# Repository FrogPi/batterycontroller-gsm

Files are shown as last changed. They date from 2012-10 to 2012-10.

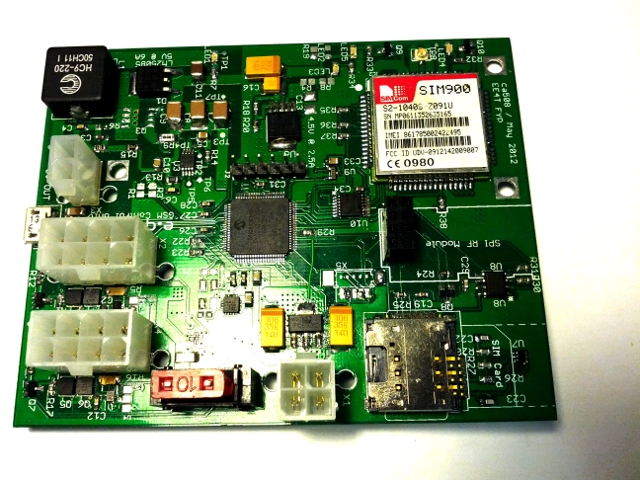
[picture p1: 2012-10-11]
media/proto.jpg

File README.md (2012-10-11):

# GSM Battery Box Monitoring and Control Board

Electrial Engineering Final Year Project Deliverable

Charith Amarasinghe 2012 <ca508@ic.ac.uk>

GSM Controller Prototype

## Features

* 1x Metered 12V Input/Output (Battery Connection)
* 2x Metered 12V Input/Outputs (Device Connection) with 4x IO pins each
* 1x 5V/3A USB Compliant Output
* Integrated SIMCOM SIM900 GSM Modem with U.FL Antenna Connector
* SPI interface for nRF24L01 RF module
* Integrated SIM and MicroSD socket
* RTCC Battery Backup
* PIC24FJ256GB106 Microcontroller with PICKit3 debug port
* microUSB OTG Port

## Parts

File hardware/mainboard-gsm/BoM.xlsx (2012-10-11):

C7 | 1843166 | 1812 Capacitor 22uF MLCC X5R | 4 | SIK
C8
C9
R14 | 1170981 | 0603 88.7K Resistor £0.011 | 50
R13 | 1652973 | 2.37k Resistor 0805 £0.082 | 4
C6 | 1740627 (http://onecall.farnell.com/avx/06031c102jat2a/capacitor-mlcc-0603-100v-1nf/dp/1740627) | 1000pF Capacitor 0603 £0.036 | 10
C10 |  | 1uF 0805 Capacitor
R9 | 1099907 | 10mOhm Resistor 1206 £0.28 | 5
C5 | 1907325 | 470nF 0805 £0.058 | 10
D1 | 9101055 | Diode Vishay 6CWO04 £1.16 | 2 | SOL
Q3 | 2101443 | MOSFET Si4401 £1.15 | 2 | SOL
L1 | 2075650 | Coiltronics 22uH Inductor £1.48 | 2 | SOL
R6 | 1399961 | 68K resistor £0.047 | 10
C4 | 1658867 | 3300pF Capacitor £0.083 | 10
R11 | 1653284 | 10K resistor £0.016 | £10.00
R15 | 1160169 | 3.4K resistor £0.32 | 5
C11 | 1907361 | 100uF Capacitor £1.07 | 5
C13 | 1658149 | 100uF Capacitor £0.195 | 5
R18 | 1170963 (http://onecall.farnell.com/multicomp/mc-0-063w-0603-1-57k6/resistor-0603-57k6/dp/1170963) | 57.6K Resistor £0.011 | 50
R20 | 2059637 (http://onecall.farnell.com/panasonic/erj3geyj223v/resistor-0603-22k-5-0-1w/dp/2059637) | 22K Resistor £0.007 | 50
C16 | 1658149 | See abv
C17 | CA06884 | 10uF Capacitor £0.19 | 10
U6 | 1822373 | Micrel LDO 3A £1.62 | 2
U5 | 2057285 | NX1117 3V3 £0.179 | 3
C14 | CA06884 | See abv
C15 | CA06884 | See abv
 | 1717778 | 2.7ohm Resistor | 5
 | 1857353 | IRFHM9331PbF £0.24 | 10
 | 1621962 | Welwyn 0.002ohm Resistor £0.33 | 5
 | 1453876 | Fuse Holder (Mini Blade) £1.6 | 2
 | 2008366 (http://onecall.farnell.com/bourns/cr0603-jw-104glf/resistor-0603-100k-5-0-1w/dp/2008366) | 100K Resistor 0603 £.009 | 50
 | 2008360 (http://onecall.farnell.com/bourns/cr0603-jw-103elf/resistor-0603-10k-5-0-1w/dp/2008360) | 10K Resistor 0603 £0.009 | 50
 | 1894721 | 2n7002 NFET £0.02 | 10
 | 2059640 (http://onecall.farnell.com/panasonic/erj3geyj303v/resistor-0603-30k-5-0-1w/dp/2059640) | 30K Resistor 0603 £0.007 | 50
 | 1833812 (http://onecall.farnell.com/avx/0805zd106kat2a/capacitor-0805-x5r-10v-10uf/dp/1833812) | 10uF Ceramic 0805 £0.08 | 10
 | 1568026 (http://onecall.farnell.com/molex/47346-0001/micro-usb-type-b-receptacle-bottom/dp/1568026) | Molex 47346-0001 MicroUSB £0.57 | 4
 | 1759321 (http://onecall.farnell.com/multicomp/mcca000443/mlcc-12065v-25v-470nf/dp/1759321) | 0.47uF 1206 Capacitor £0.027 | 10
 | 1576869 | Pic24FJ256GB106 £4.50 | 2
 | 1470321 | Voltage Reference £1.06 | 2
 | 2064725 | Battery Holder SMT £0.33 | 5
 | 9556923 | Diode £0.39 | 5
 | 2064064 | Sim/MicroSD Combo £1.86 | 2
 | 1972673 | MOSFET £0.093 | 4
 | 1455038 | Dataflash £2.10 | 1
 | 1236302 | Buffer £0.33 | 4
 | 2059033 | SMF05C ESD Prot £0.29 | 4
 | 2059557 (http://onecall.farnell.com/panasonic/erj3geyj220v/resistor-0603-22r-5-0-1w/dp/2059557) | 22ohm Resistor £0.007 | 50
 | 1907288 (http://onecall.farnell.com/tdk/c1608c0g1h220j/capacitor-0603-c0g-50v-22pf/dp/1907288) | 22pF 0603 Capacitor £0.011 | 50
 | 1226420 (http://onecall.farnell.com/osram/lyr971-z/led-smd-yellow/dp/1226420) | 0805 LED Yellow £0.07 | 10
 | SC08080 (http://onecall.farnell.com/kingbright/kp-2012ec/led-smd-0805-std-red-clear/dp/SC08080) | 0805 LED Red £0.07 | 10
 | 2099239 (http://onecall.farnell.com/kingbright/kpt-2012sgc/led-green-0805-smd/dp/2099239) | 0805 LED Green £0.04 | 10
 | 2099227 (http://onecall.farnell.com/kingbright/kpt-1608yc/led-yellow-0603-smd/dp/2099227) | 0603 LED Yellow £0.05 | 10
 | 2099221 (http://onecall.farnell.com/kingbright/kpt-1608ec/led-red-0603-smd/dp/2099221) | 0603 LED Red £0.05 | 10
 | 1593489 (http://onecall.farnell.com/multicomp/2214s-08sg-85/socket-pcb-2-row-vert-8way/dp/1593489) | 8Way Socket Multicomp £0.54 | 5
 | CN13825 | 8Way Molex £0.22 | 4
 | CN13835 (http://onecall.farnell.com/molex/39-01-3048/receptacle-mini-fit-dual-row-4way/dp/CN13835) | 4Way Molex £0.11 | 3
 | CN13834 (http://onecall.farnell.com/molex/39-01-3028/receptacle-mini-fit-dual-row-2way/dp/CN13834) | 2Way Molex £0.11 | 4
 | 9732110 | 8 Way Molex Header £0.74 | 4
 | 9732080 (http://onecall.farnell.com/molex/39-28-1023/header-mini-fit-2way/dp/9732080) | 2 Way Molex Header £0.29 | 4
 | 9732098 (http://onecall.farnell.com/molex/39-28-1043/header-mini-fit-4way/dp/9732098) | 4 Way Molex Header £0.39 | 3

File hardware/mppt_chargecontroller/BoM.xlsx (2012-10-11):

LT3652 Charger |  |  |  |  |  | Date: | 2012-02-29
 |  |  |  |  |  | Schematic: | MiniBoxV1
Ref. | Group | Qty | Description | Cost | Vendor | Order Code | Notes
CONN1 | Ref (http://www.cpcares.com/pdf/1918.pdf) | 1 | Header 2.5mm SPOX, WTB, RA, F/lock, 2w | £0.07 | RS | 687-8086 | Mates W. 679-5896 (Pack of 10)
 |  | 1 | 2.5mm,housing,SPOX,low profile,f/lock,2w | £0.02 | RS | 679-5896 | Pack of 10
 |  | 2 | Crimp terminal, 2.5mm SPOX WTB,reel | £0.01 | RS | 687-7152 | Bag of 100
CONN2 | Ref (http://www.molex.com/molex/products/datasheet.jsp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) | 1 | 8 way vertical PCB header,Mini-Fit Jr | £0.77 | Onecall | 9732110 |  | 0.54
 | Ref (http://www.molex.com/molex/products/datasheet.jsp?part=active/0039012080_CRIMP_HOUSINGS.xml) | 1 | MOLEX - 39-01-2080 - RECEPTACLE, , 8WAY, CRIMP, MINI-FIT | £0.22 | Onecall | CN13825
 |  |  | Molex 5556T2/5556PBT2 Crimps |  |  | 9732195 | Box of 100 ~ £5
U2, U3 |  | 2 | 2N7002E N-FET | £0.03 | Onecall | 1894721 | Footprint Offset Pin 2
U1 |  | 1 | LT3652E | £6.75 | Onecall | 1839126
D1,D5 |  | 2 | MBRS340T3 | £0.34 | Onecall | 9557377 |  | 0.24
D2 |  | 1 | PMBD914 | £0.06 | Onecall | 8737800 |  | 0.032
D3 |  | 1 | BZX84C6V2L | £0.08 | Onecall | 1651586 |  | 0.059
D4 |  | 1 | BAW56 | £0.11 | Onecall | 1081213 |  | 0.052
L1 |  | 1 | SDR1006--220ML | £0.62 | Onecall | 1828080 | 22uH | 0.49
C1 |  | 1 | 4.7uF 1206 | £0.04 | Onecall | 1759452 | m10 | 0.035
C2 |  | 1 | 33uF Panasonic F series (Case D) | £0.35 | Onecall | 1539495 | m10 | 0.3
C3 |  | 1 | 50pF 0603 | £0.02 | Onecall | CA07688 | m10 | 0.014
C4 |  | 1 | 10uF 1206 | £0.17 | Onecall | 1833825 | 10 | 0.083
C5 |  | 1 | 100uF Panasonic F series (Case F) | £0.68 | Onecall | 1539512 | 10 | 0.68
C6 |  | 1 | 1uF 0805 | £0.03 | Onecall | 1828853 | 10 | 0.019
R1 |  | 1 | 499K 0603 1% | £0.01 | Onecall | 1171055 | 50
R2 |  | 1 | 100K 0603 1% | £0.06 | Onecall | 1652826 | 1 | 0.024
R3 |  | 1 | 0 ohm | £0.01 |  | 2008343
R4 |  | 1 | DNP
R5 |  | 1 | 309K 0805 0.1% | £0.10 | Onecall | 1576071 | 5 | 0.09 | SOL | 3
R6 |  | 1 | 174K 0805 0.1% | £0.04 | Onecall | 1576042 | 5 | 0.032 | SOL | 3
R7 |  | 1 | 100k 0805 0.1% | £0.18 | Onecall | 2008315 | 5 | 0.125 | SOL | 3
R8 |  | 1 | 1M 0805 1% | £0.02 | Onecall | 1506149 | 10 | 0.018 | SOL | 8
R9 |  | 1 | 0.06 2512 1% | £0.54 | Onecall | 1717955 | 5 | 0.4 |  |  | Wrong
R10 |  |  | DNP
R11, R14 |  | 2 | 2.7K 0603 | £0.01 | Onecall | 9334262 | 50 |  | SOL | 46
R12, R13 |  | 2 | 4.7K 0805 | £0.01 | Onecall | 1469923 | 50 |  | SOL | 45

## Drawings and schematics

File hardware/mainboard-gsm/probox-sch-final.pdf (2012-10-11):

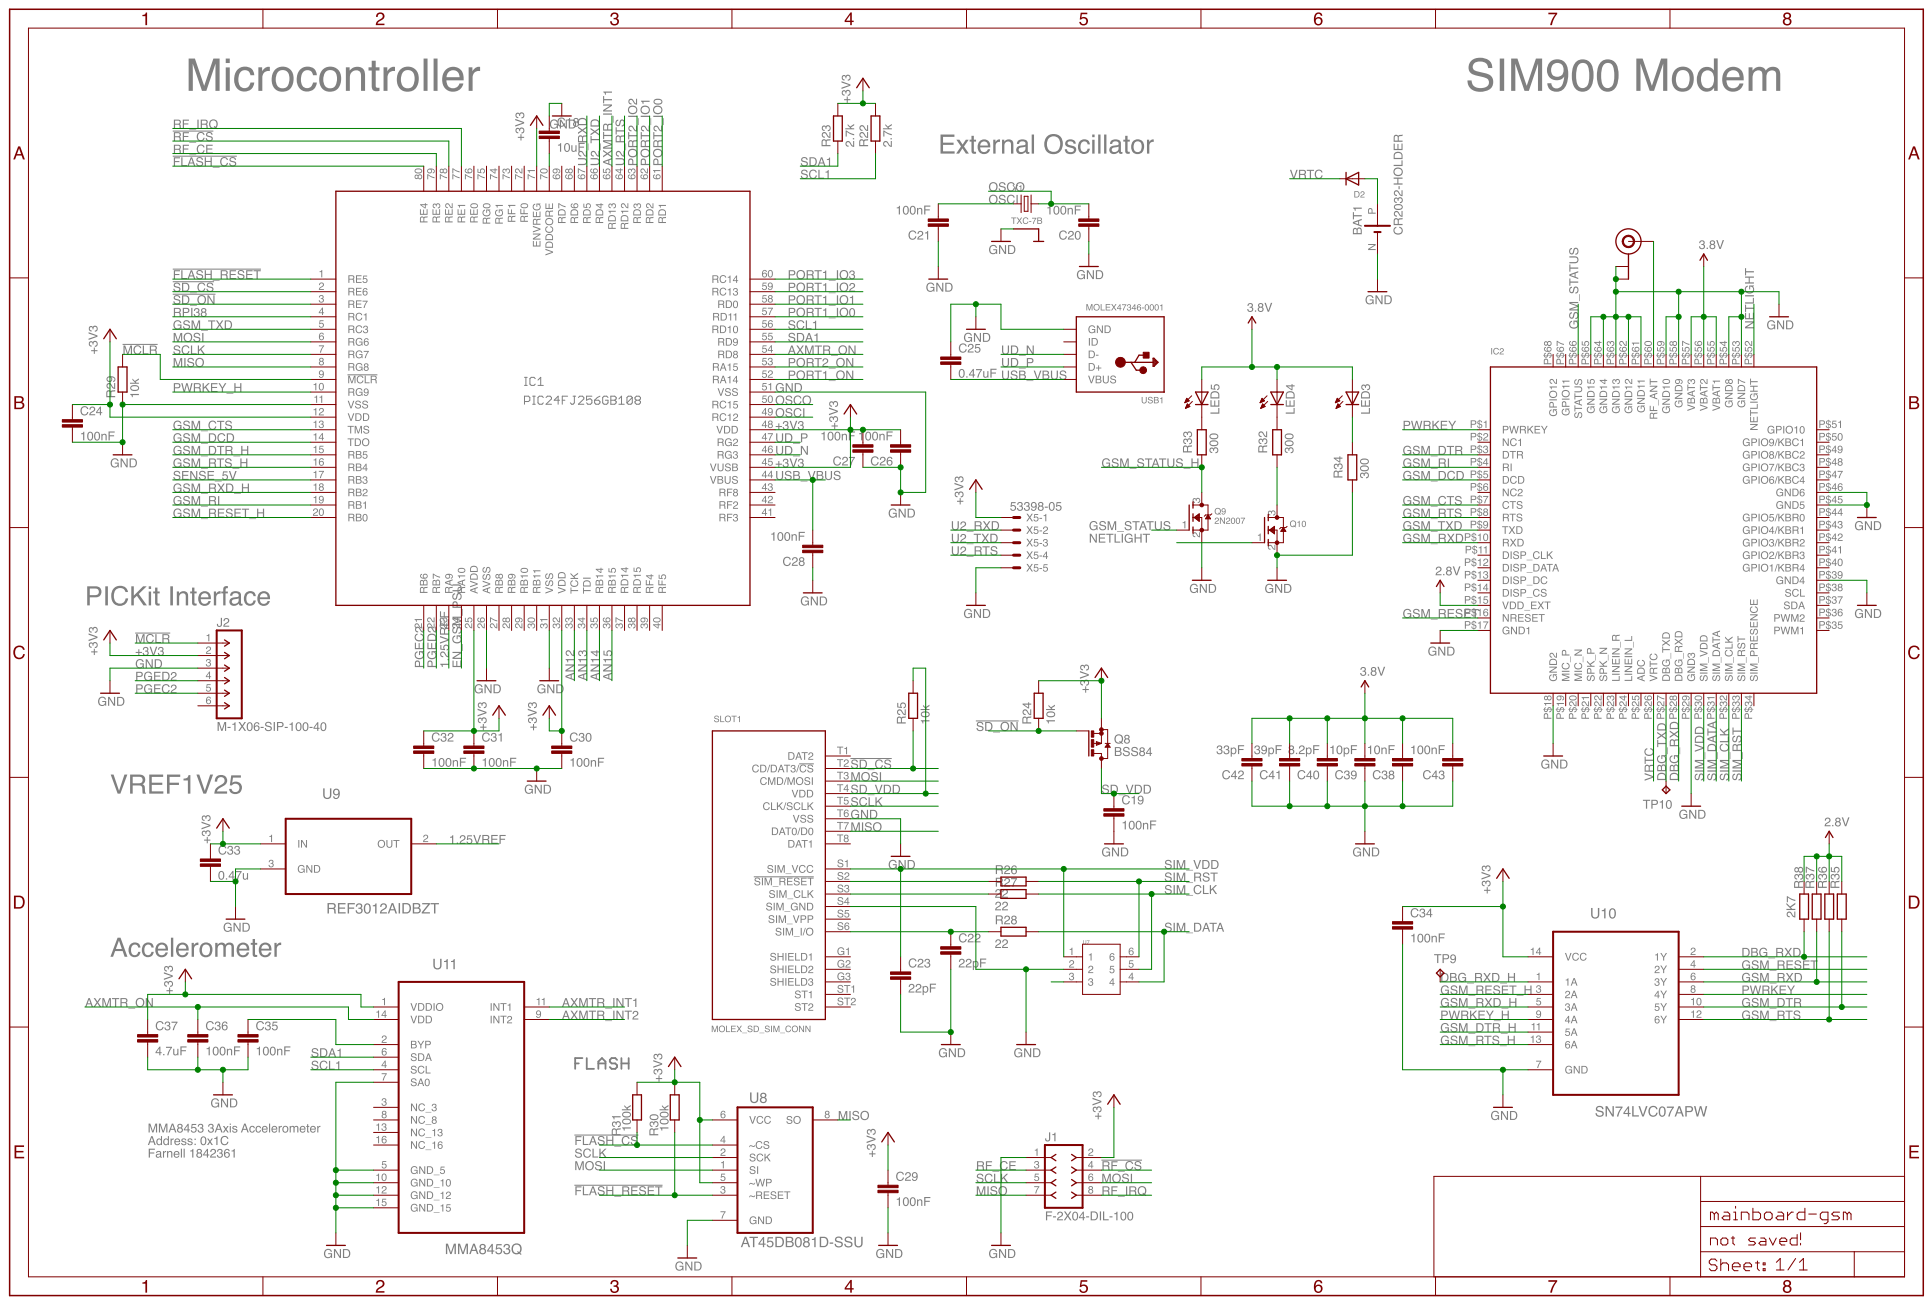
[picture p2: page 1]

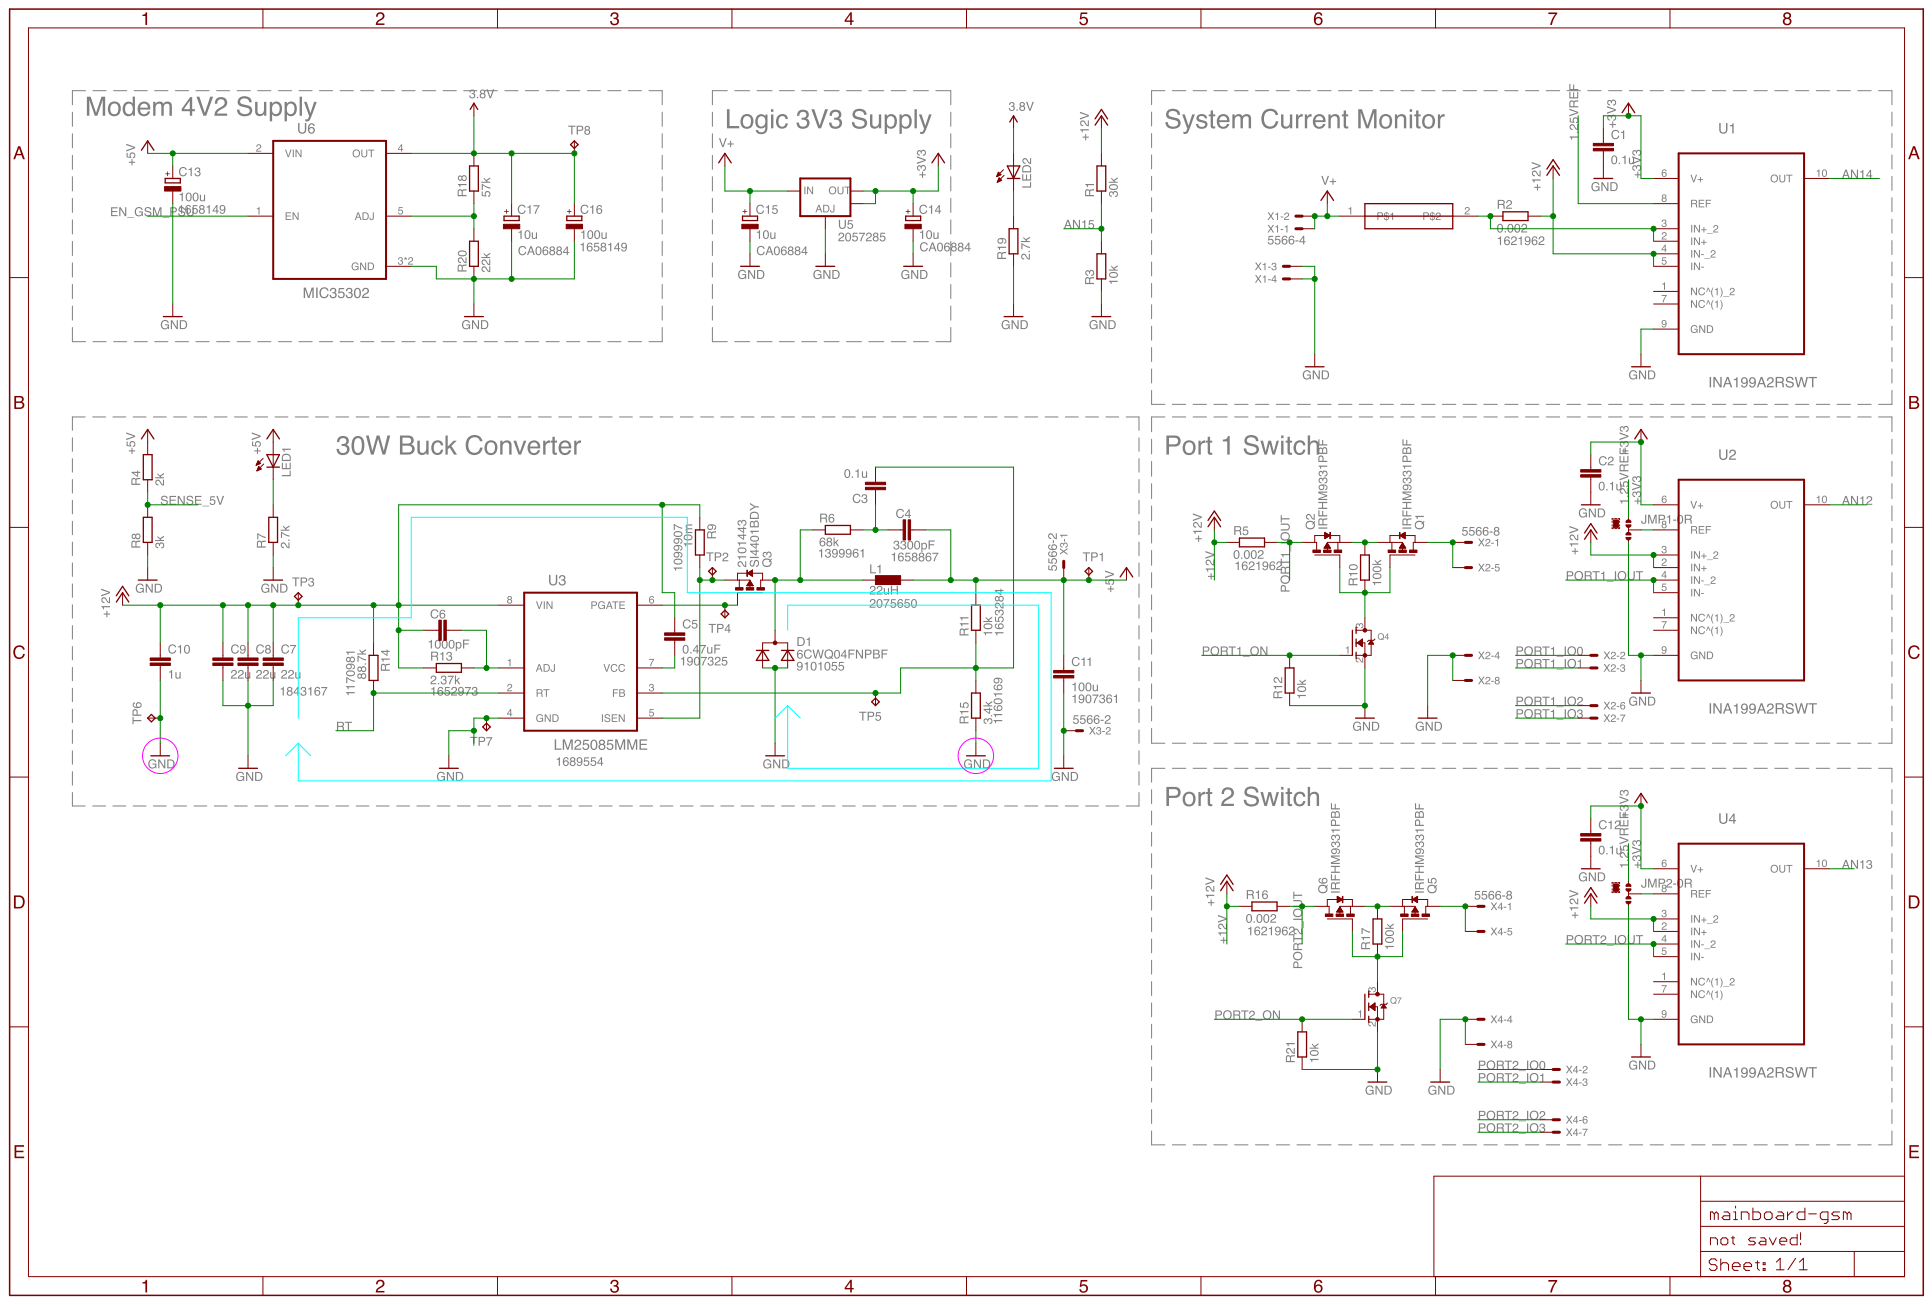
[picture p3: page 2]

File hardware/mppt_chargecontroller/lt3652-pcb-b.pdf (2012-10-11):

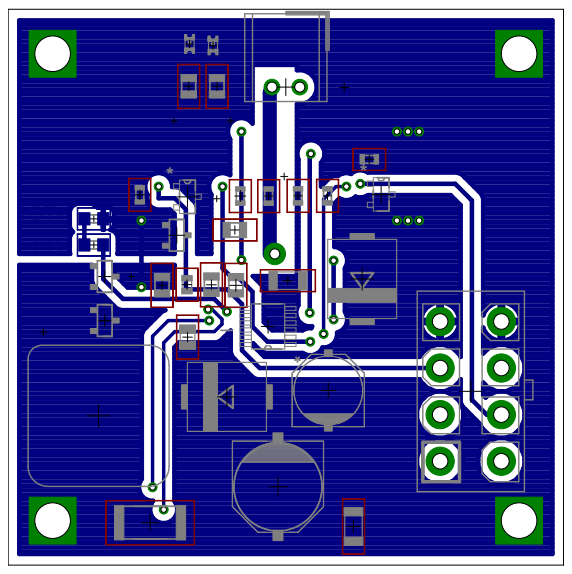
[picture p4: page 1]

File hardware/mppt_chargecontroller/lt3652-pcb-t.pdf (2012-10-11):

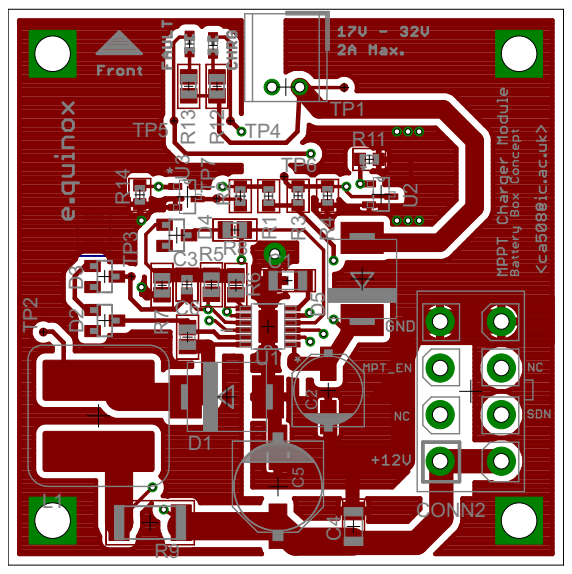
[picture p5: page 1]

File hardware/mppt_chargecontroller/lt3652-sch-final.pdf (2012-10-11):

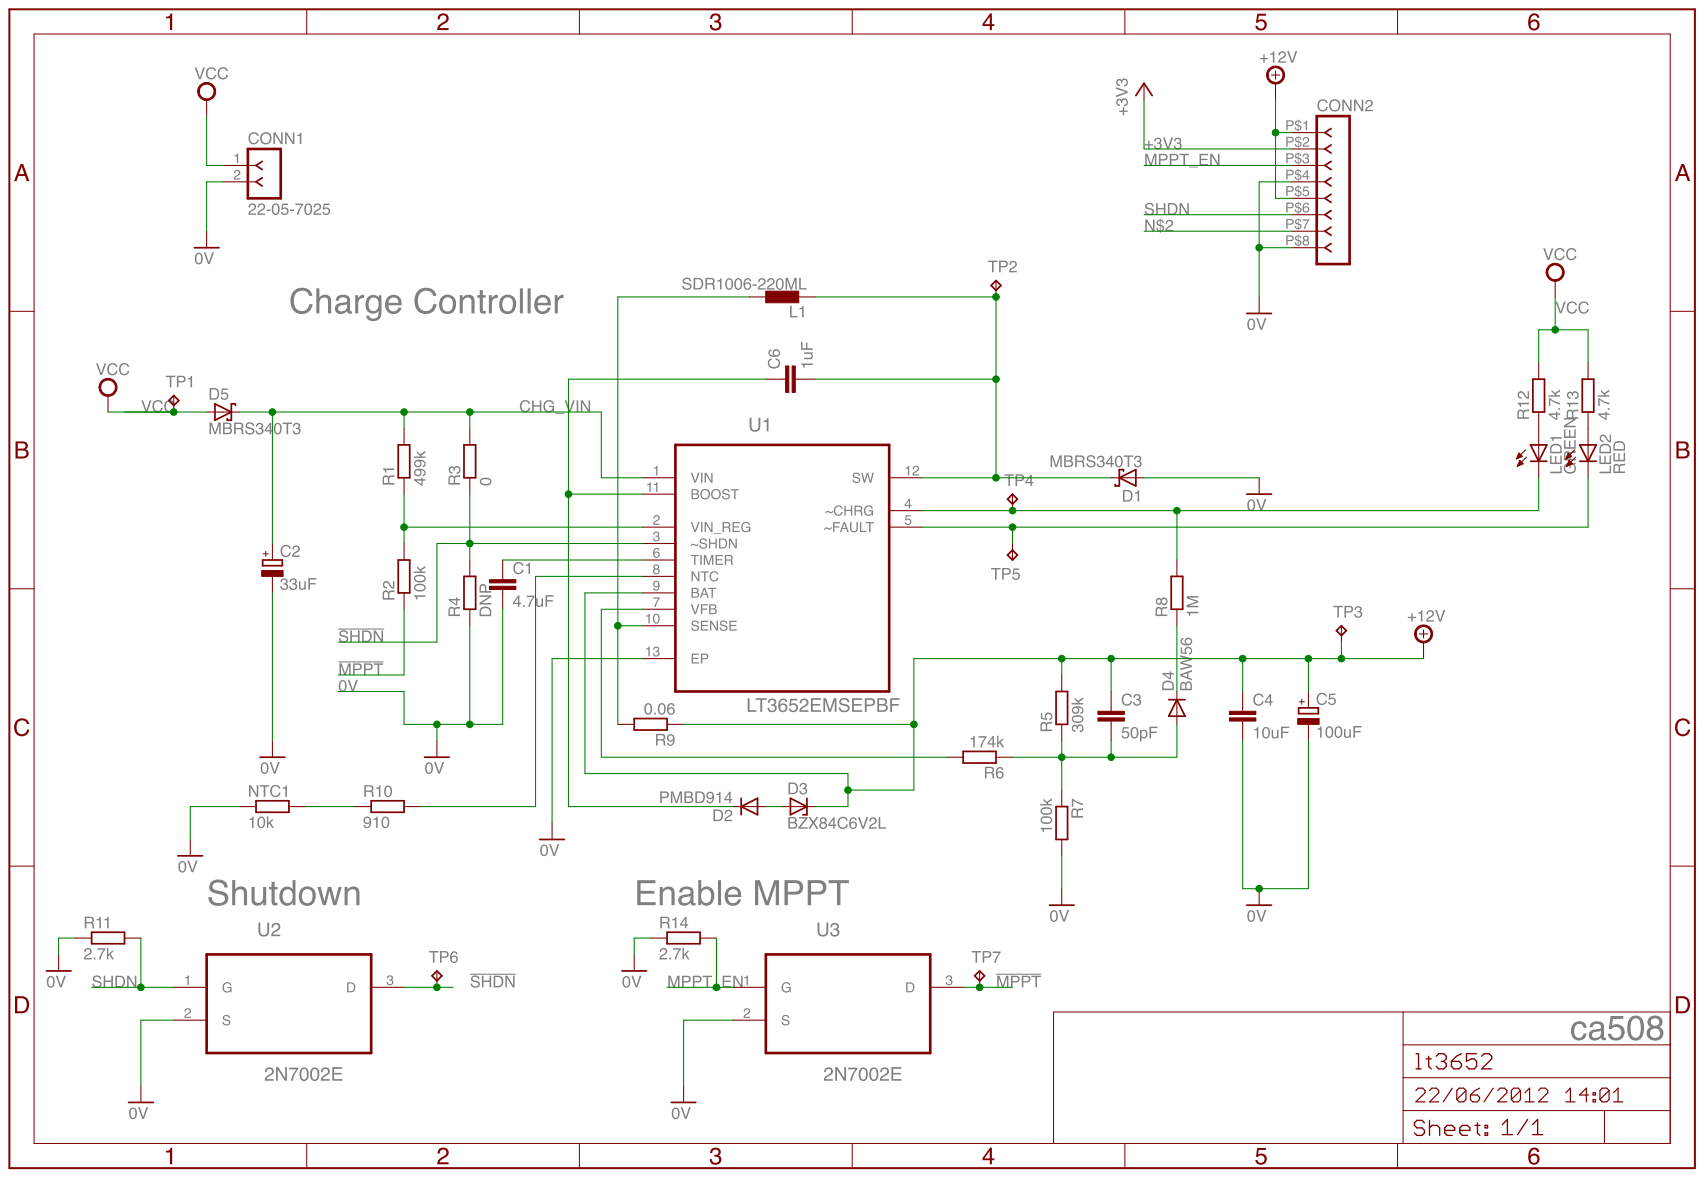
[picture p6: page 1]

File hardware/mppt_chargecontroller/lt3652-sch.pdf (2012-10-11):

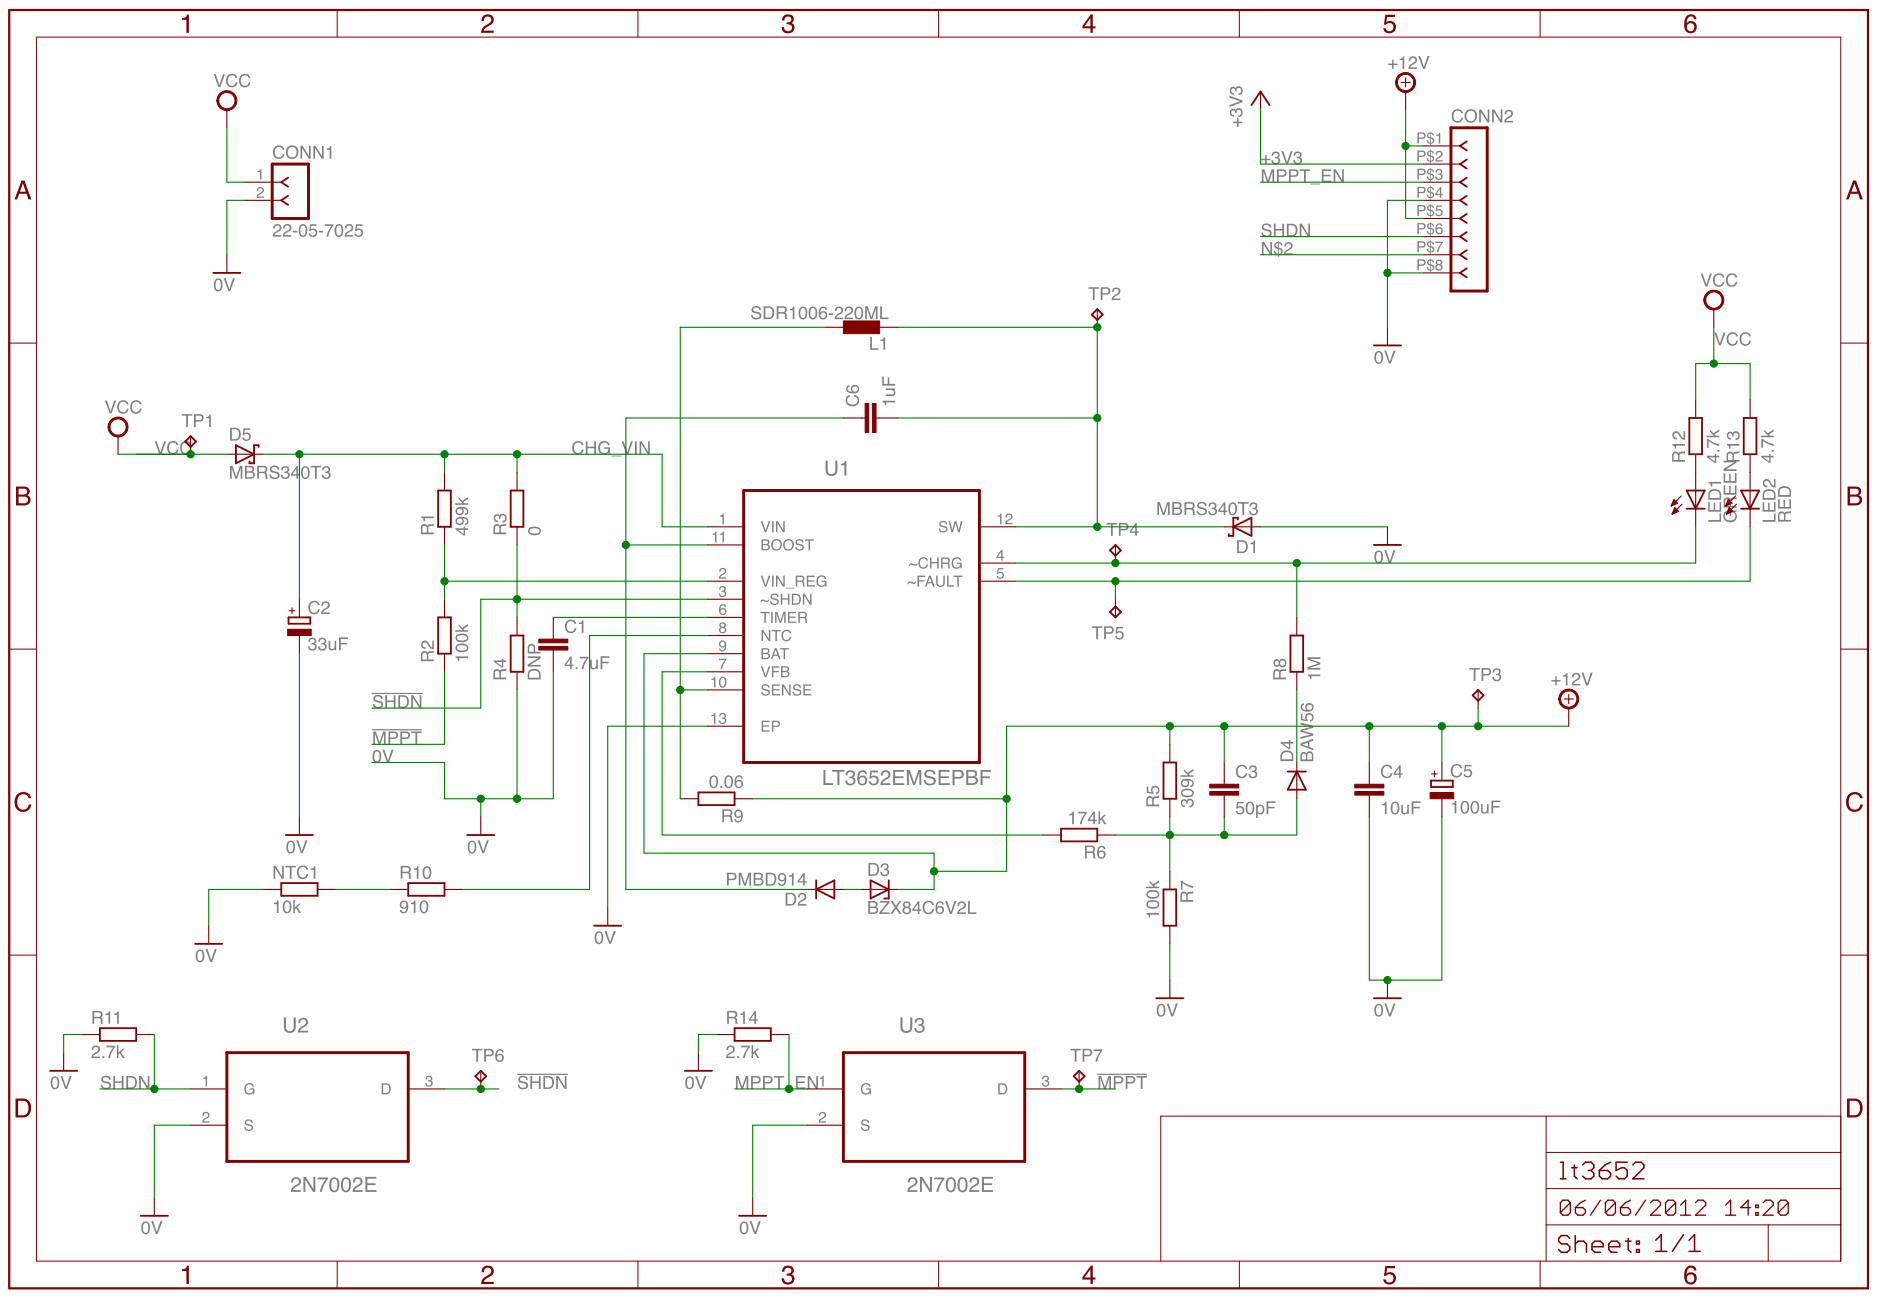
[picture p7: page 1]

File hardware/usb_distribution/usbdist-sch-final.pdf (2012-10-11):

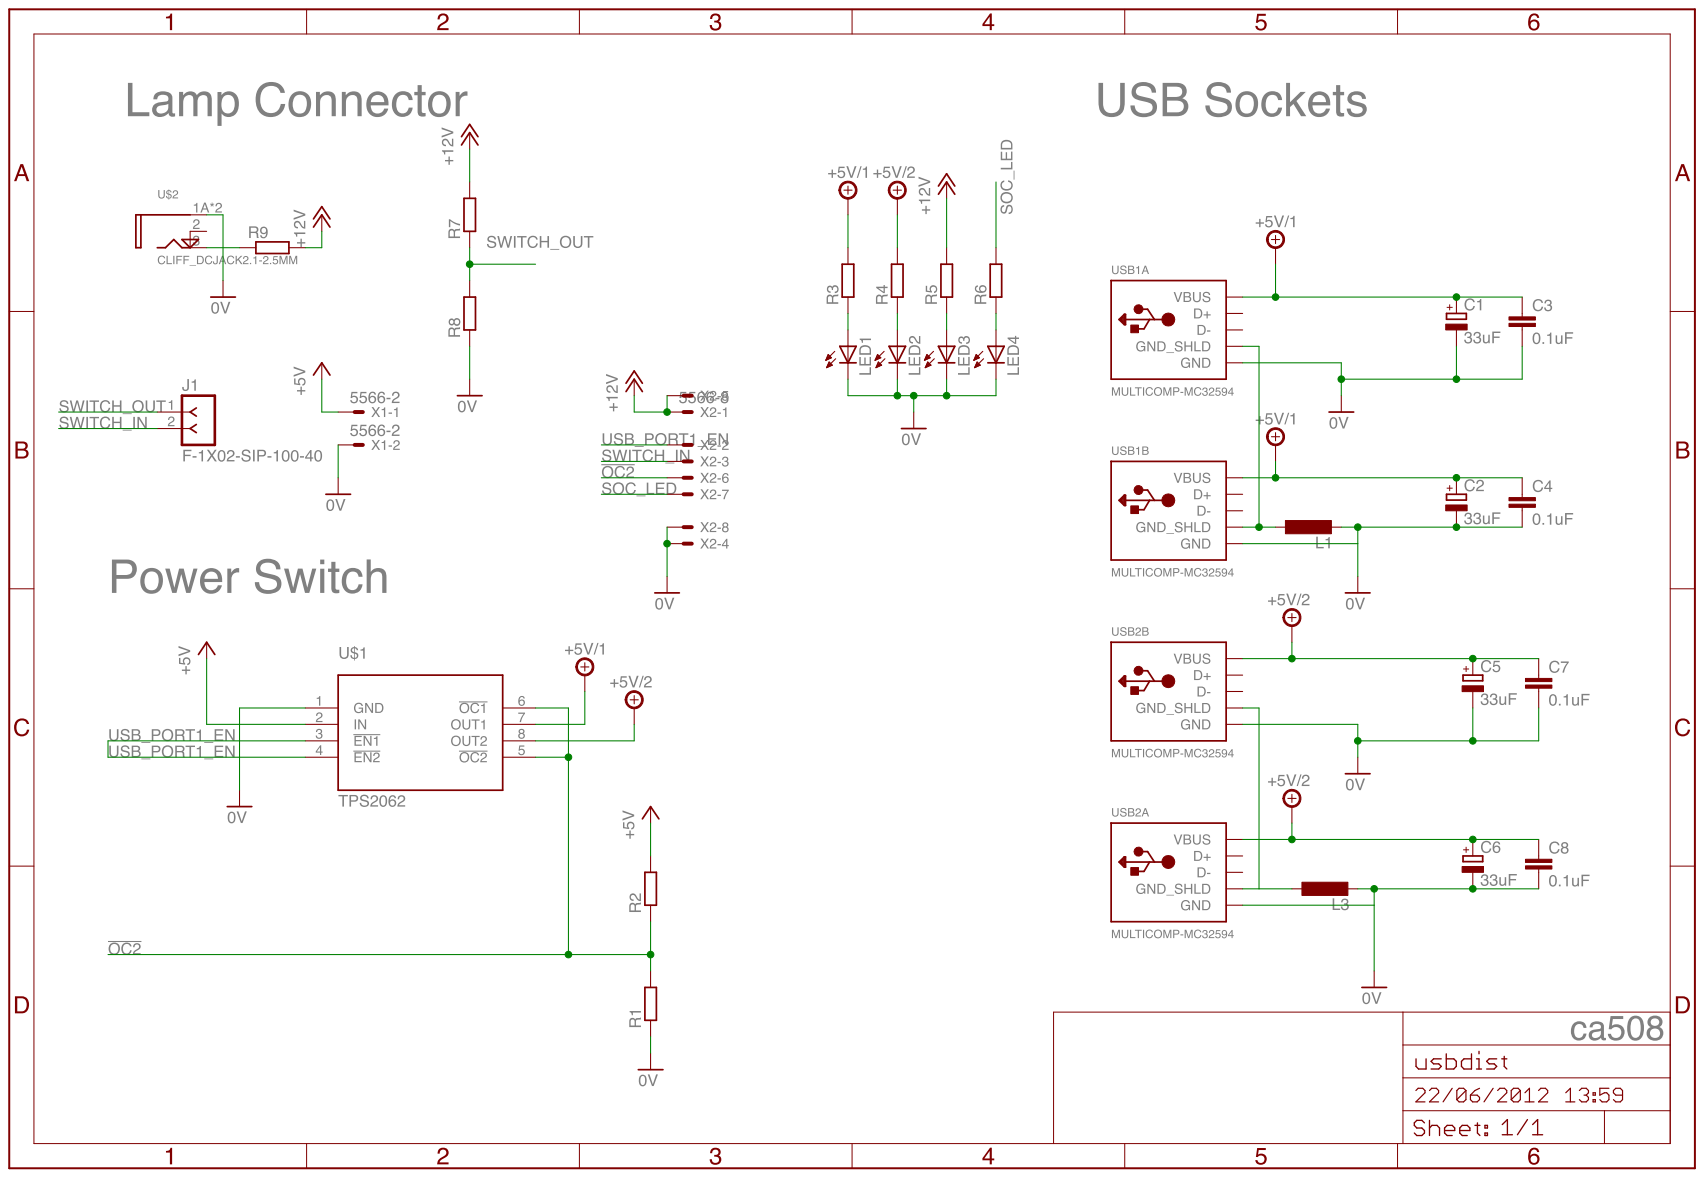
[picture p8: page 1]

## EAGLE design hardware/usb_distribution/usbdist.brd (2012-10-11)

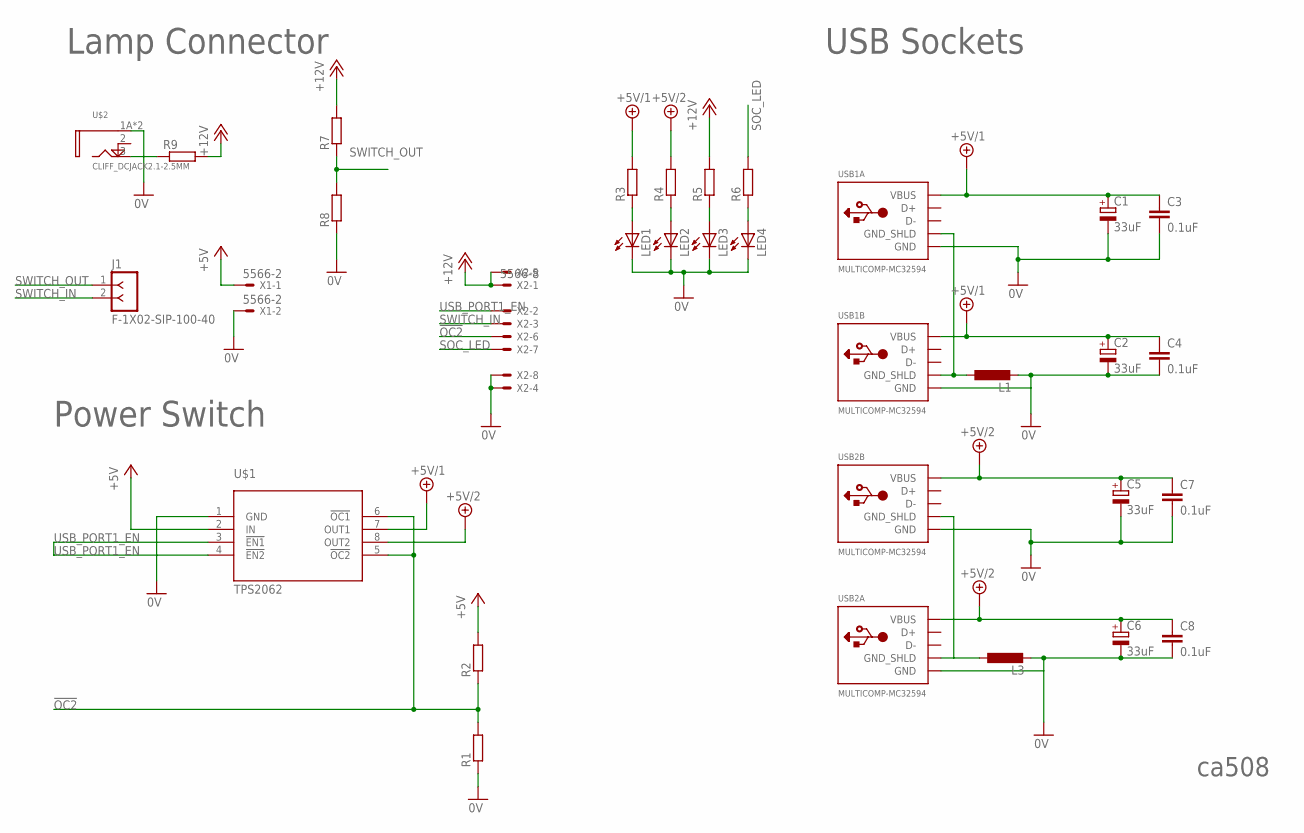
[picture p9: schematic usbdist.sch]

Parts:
C1, C2, C5, C6: 33uF; B/3528-21R; FARNELL 1672547
C3, C4, C7, C8: 0.1uF; C0603
J1: F-1X02-SIP-100-40; SIP-100-02-40
L1, L3: L-EUL2012C; L2012C
LED1, LED2, LED3, LED4: LEDCHIP-LED0805; CHIP-LED0805
R1, R2, R3, R4, R5, R6, R7, R8: R-EU_R0805; R0805
R9: R-EU_0204/5; 0204/5
U$1: TPS2062; SO8; FARNELL 1560652
U$2: CLIFF_DCJACK2.1-2.5MM; FC6814XS
USB1, USB2: MULTICOMP-MC32594; MC32594
X1: 5566-2
X2: 5566-8

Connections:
0V: C1.-, C2.-, C3.2, C4.2, C5.-, C6.-, C7.2, C8.2, L1.2, L3.2, LED1.C, LED2.C, LED3.C, LED4.C, R1.1, R8.1, U$1.1 (GND), U$2.1A (SLEEVE), U$2.1B (SLEEVE), USB1.USB1-4 (GND), USB1.USB2-4 (GND), USB2.USB1-4 (GND), USB2.USB2-4 (GND), X1.2, X2.4, X2.8
!OC2!: R1.2, R2.1, U$1.5 (!OC2!), U$1.6 (!OC1!), X2.6
+5V: R2.2, U$1.2 (IN), X1.1
+5V/1: C1.+, C2.+, C3.1, C4.1, R3.2, U$1.7 (OUT1), USB1.USB1-1 (VBUS), USB1.USB2-1 (VBUS)
+5V/2: C5.+, C6.+, C7.1, C8.1, R4.2, U$1.8 (OUT2), USB2.USB1-1 (VBUS), USB2.USB2-1 (VBUS)
+12V: R5.2, R7.2, R9.2, X2.1, X2.5
unnamed: L1.1, USB1.P$1 (GND_SHLD), USB1.P$2 (GND_SHLD), USB1.P$3 (GND_SHLD), USB1.P$4 (GND_SHLD)
unnamed: LED3.A, R5.1
unnamed: LED2.A, R4.1
unnamed: LED1.A, R3.1
unnamed: LED4.A, R6.1
unnamed: L3.1, USB2.P$1 (GND_SHLD), USB2.P$2 (GND_SHLD), USB2.P$3 (GND_SHLD), USB2.P$4 (GND_SHLD)
unnamed: R9.1, U$2.3 (TIP)
SHUNT: U$2.2 (SHUNT)
SOC_LED: R6.2, X2.7
SWITCH_IN: J1.2, X2.3
SWITCH_OUT: J1.1, R7.1, R8.2
USB_PORT1_EN: U$1.3 (!EN1!), U$1.4 (!EN2!), X2.2

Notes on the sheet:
Power Switch
Lamp Connector
USB Sockets
ca508

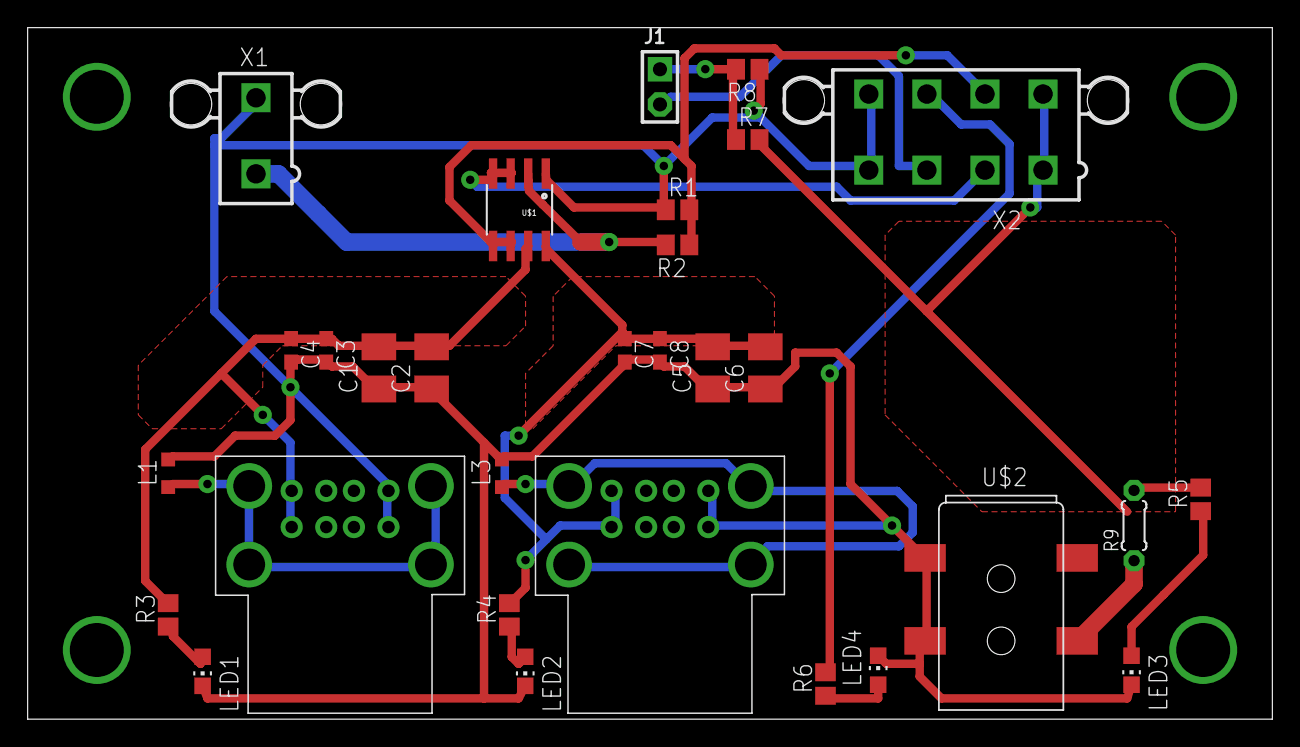
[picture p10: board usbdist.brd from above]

Board: 2 copper layers, 90.0 x 50.0 mm, 30 parts (0 on the bottom side), 17 nets.

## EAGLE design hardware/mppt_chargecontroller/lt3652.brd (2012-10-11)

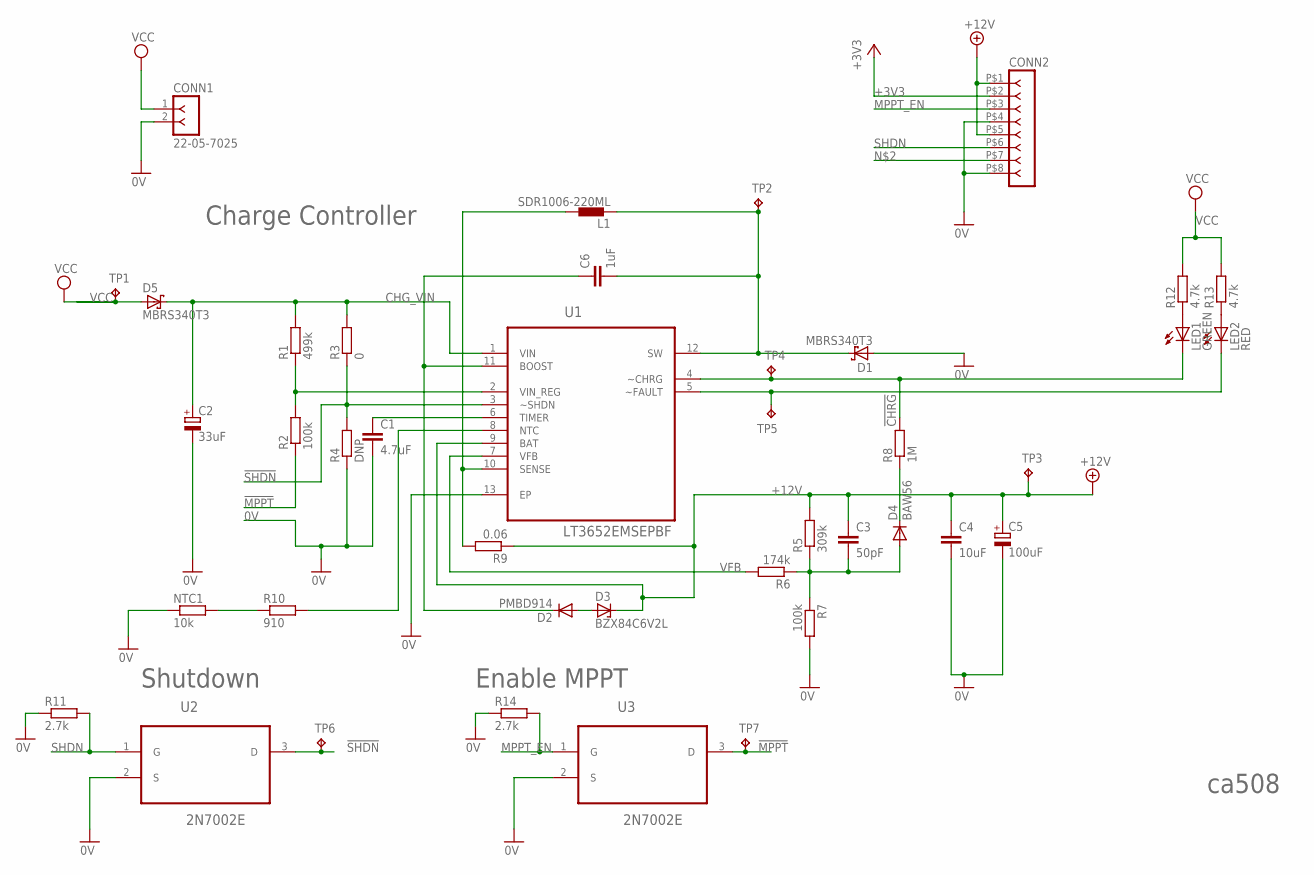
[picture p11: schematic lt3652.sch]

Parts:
C1: 4.7uF; C1206
C2: 33uF; PANASONIC_D
C3: 50pF; C0603
C4: 10uF; C1206
C5: 100uF; PANASONIC_F
C6: 1uF; C0805
CONN1: 22-05-7025
CONN2: 39-28-1083
D1, D5: MBRS340T3; SMC
D2: PMBD914; SOT23
D3: BZX84C6V2L; SOT23
D4: BAW56; SOT23
L1: SDR1006-220ML; SDR1006
LED1: GREEN; CHIPLED_0603
LED2: RED; CHIPLED_0603
NTC1: 10k; R0603
R1: 499k; R0603
R2: 100k; R0603
R3: 0; R0603
R4: DNP; R0603
R5: 309k; R0805
R6: 174k; R0805
R7: 100k; R0805
R8: 1M; R0805
R9: 0.06; R2512
R10: 910; R0603
R11, R14: 2.7k; R0603
R12, R13: 4.7k; R0805
TP1, TP2, TP3, TP4, TP5, TP6, TP7: TPTP07R; TP07R
U1: LT3652EMSEPBF; SOP65P490X110-13N
U2, U3: 2N7002E; SOT95P230X110-3N

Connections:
0V: C1.2, C2.-, C4.2, C5.-, CONN1.2, CONN2.P$4 (4), CONN2.P$8 (8), D1.A, NTC1.1, R4.1, R7.2, R11.1, R14.1, U1.13 (EP), U2.2 (S), U3.2 (S)
!CHRG: LED1.C, R8.2, TP4.TP, U1.4 (~CHRG)
!MPPT!: R2.1, TP7.TP, U3.3 (D)
!SHDN!: R3.1, R4.2, TP6.TP, U1.3 (~SHDN), U2.3 (D)
+3V3: CONN2.P$2 (2)
+12V: C3.1, C4.1, C5.+, CONN2.P$1 (1), CONN2.P$5 (5), D3.3 (C), R5.2, R9.1, TP3.TP, U1.9 (BAT)
CHG_VIN: C2.+, D5.C, R1.2, R3.2, U1.1 (VIN)
MPPT_EN: CONN2.P$3 (3), R14.2, U3.1 (G)
unnamed: R1.1, R2.2, U1.2 (VIN_REG)
unnamed: C6.2, D1.C, L1.P$1 (1), TP2.TP, U1.12 (SW)
unnamed: C1.1, U1.6 (TIMER)
unnamed: C6.1, D2.3 (C), U1.11 (BOOST)
unnamed: R10.2, U1.8 (NTC)
unnamed: D2.1 (A), D3.1 (A)
unnamed: L1.P$2 (2), R9.2, U1.10 (SENSE)
unnamed: C3.2, D4.1 (A), R5.1, R6.1, R7.1
unnamed: D4.3 (C), R8.1
unnamed: LED2.C, TP5.TP, U1.5 (~FAULT)
unnamed: NTC1.2, R10.1
unnamed: LED1.A, R12.1
unnamed: LED2.A, R13.1
SHDN: CONN2.P$6 (6), R11.2, U2.1 (G)
VCC: CONN1.1, D5.A, R12.2, R13.2, TP1.TP
VFB: R6.2, U1.7 (VFB)

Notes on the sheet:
ca508
Shutdown
Enable MPPT
Charge Controller

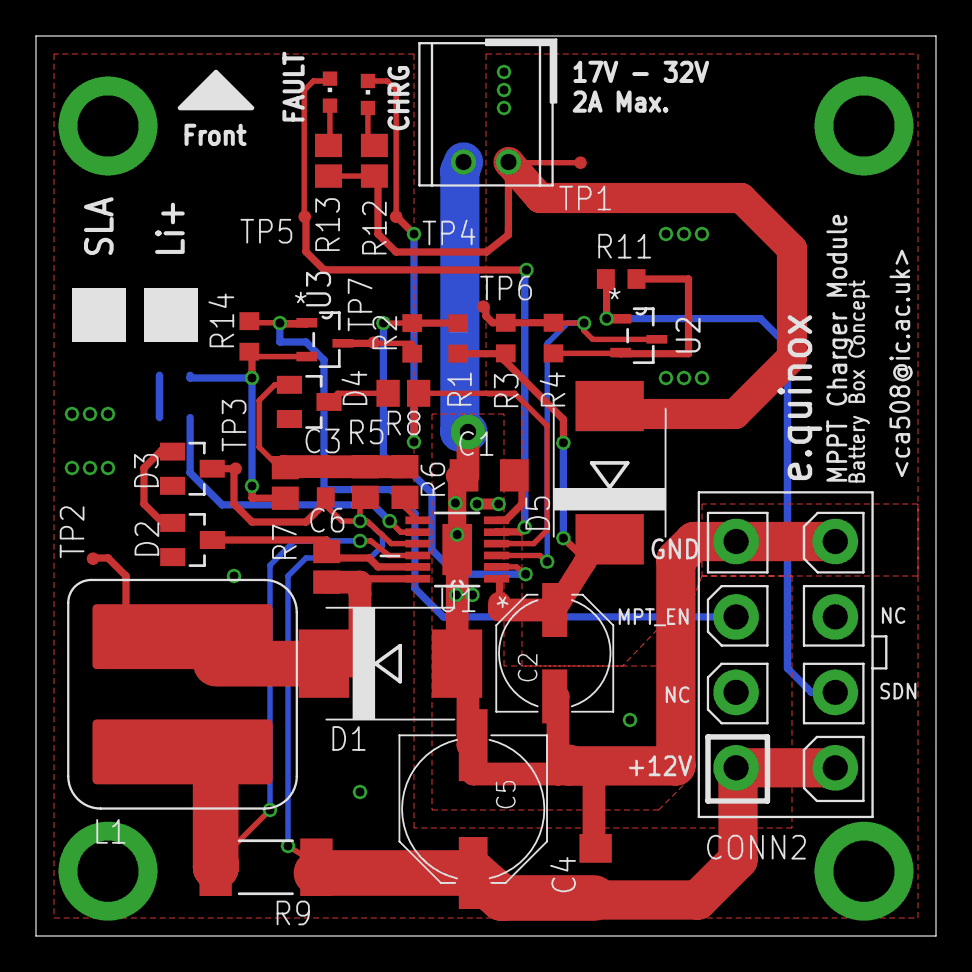
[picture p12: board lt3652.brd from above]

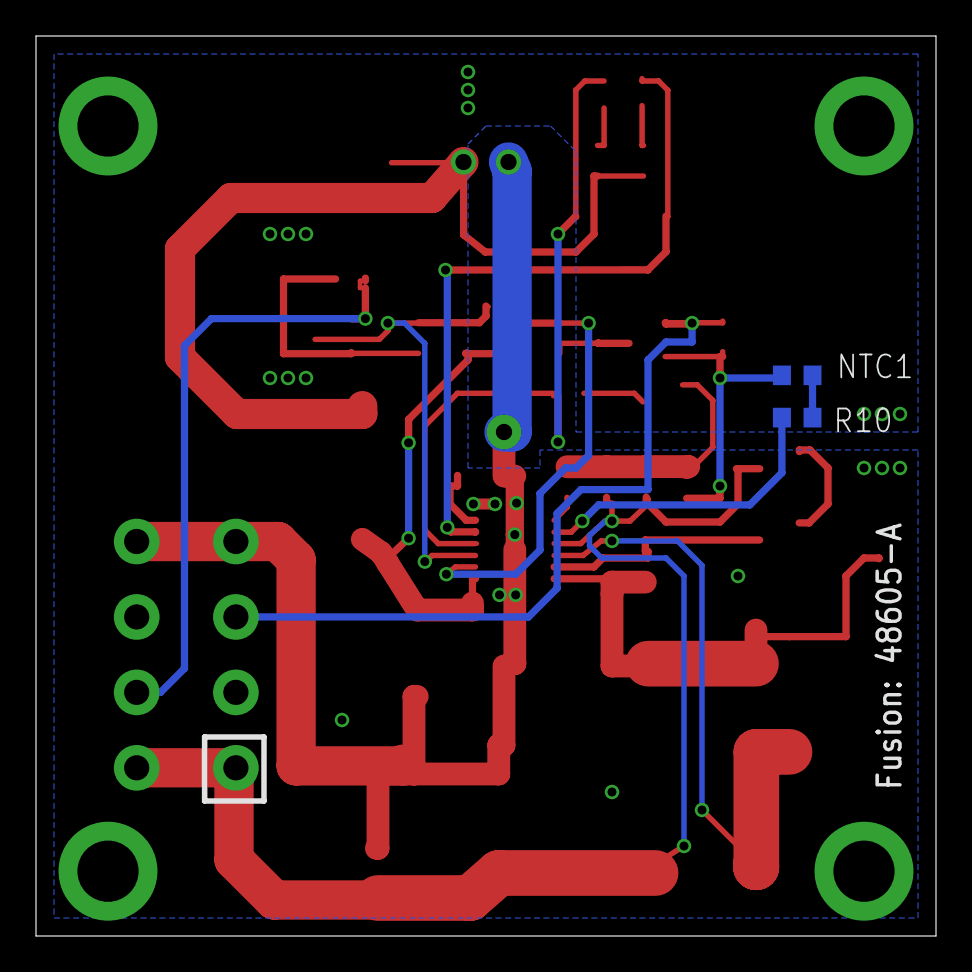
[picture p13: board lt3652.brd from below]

Board: 2 copper layers, 50.0 x 50.0 mm, 41 parts (2 on the bottom side), 23 nets.

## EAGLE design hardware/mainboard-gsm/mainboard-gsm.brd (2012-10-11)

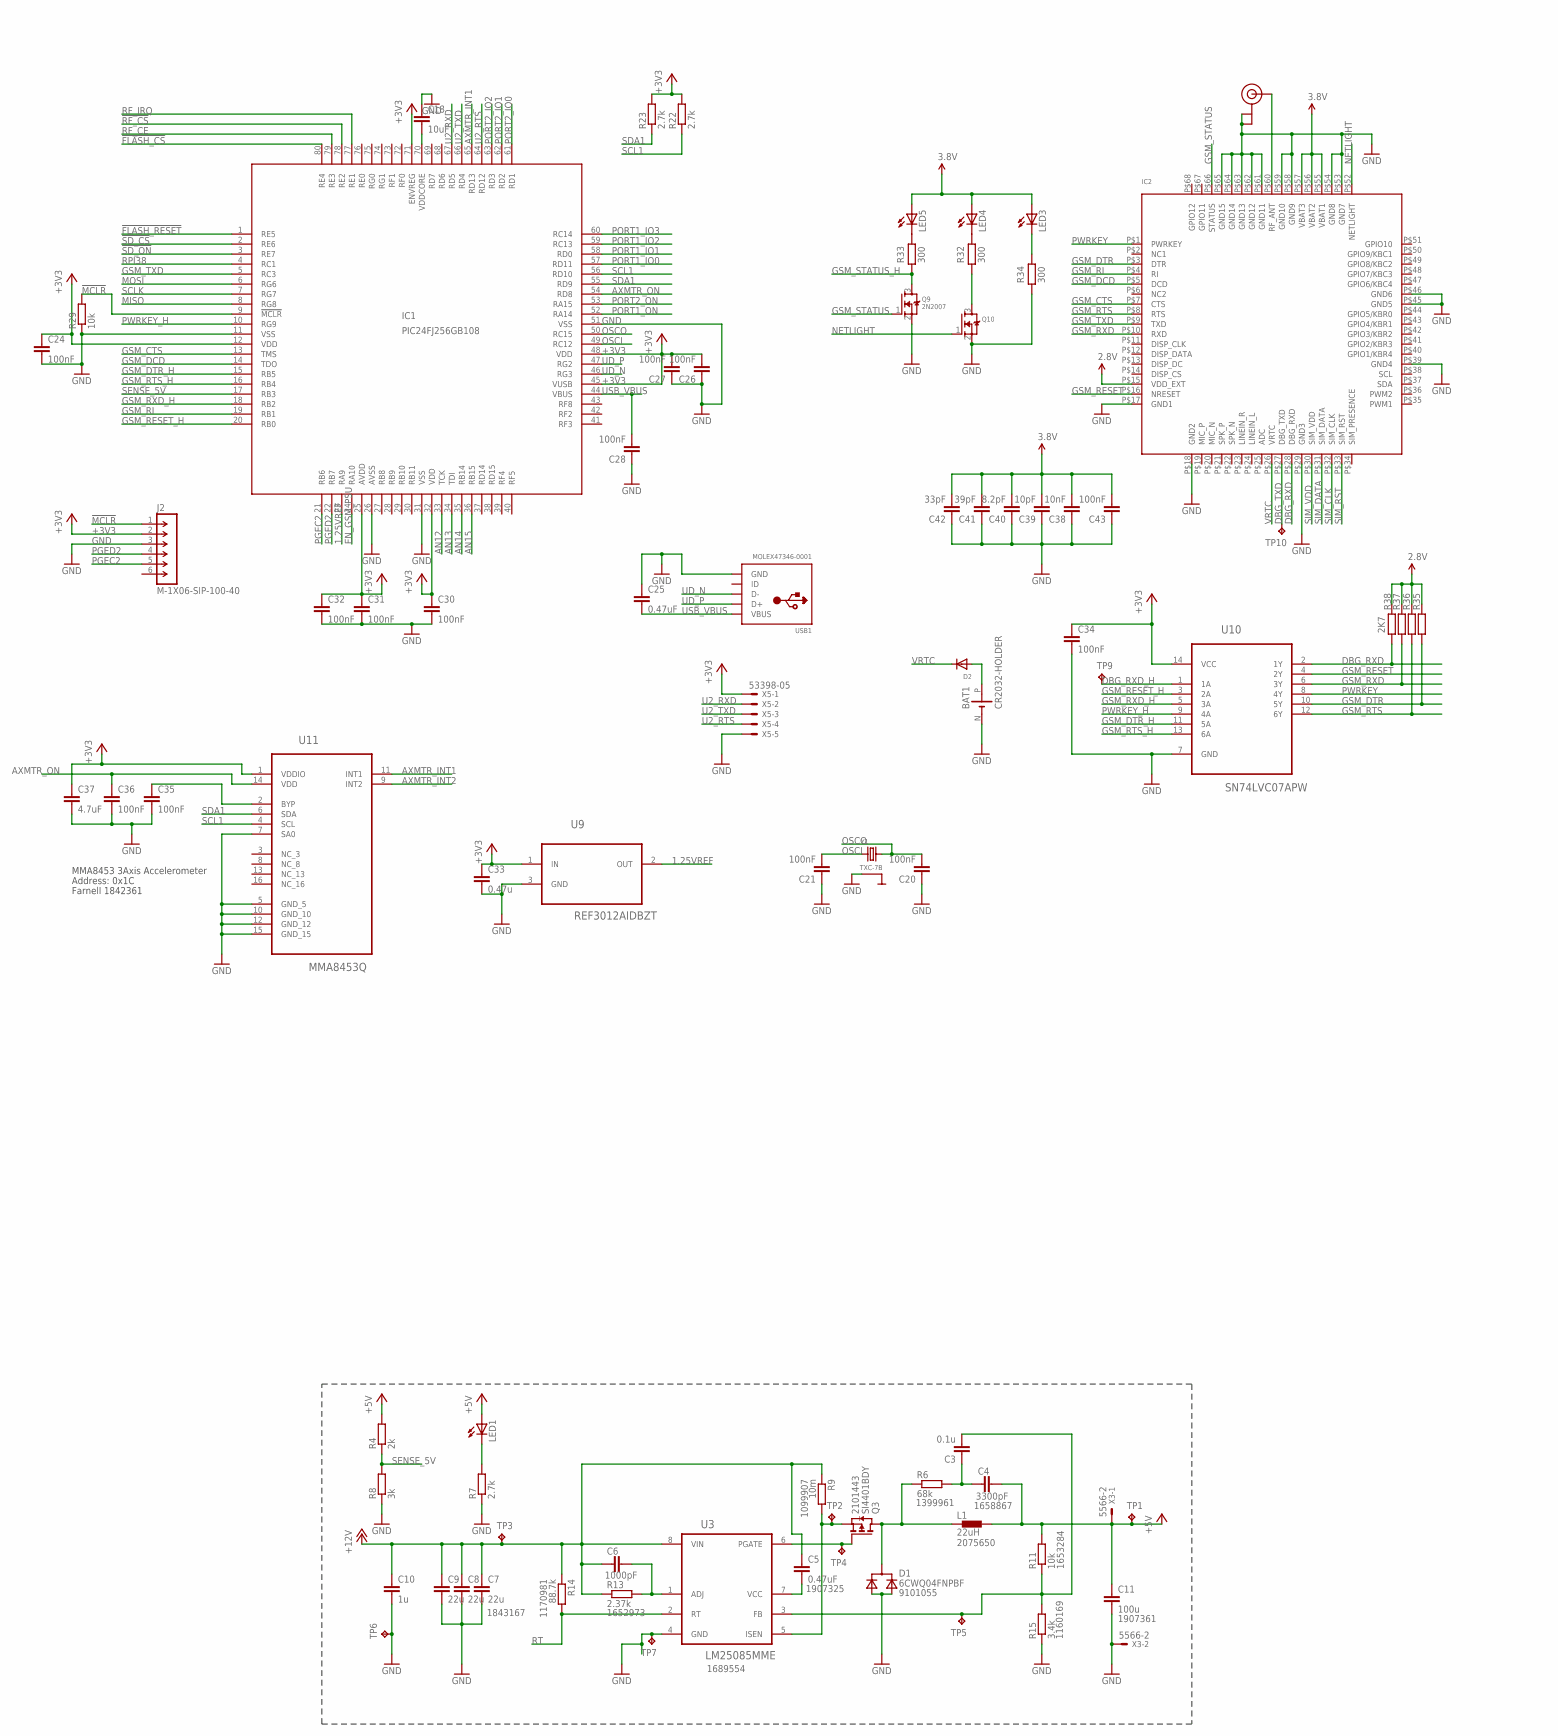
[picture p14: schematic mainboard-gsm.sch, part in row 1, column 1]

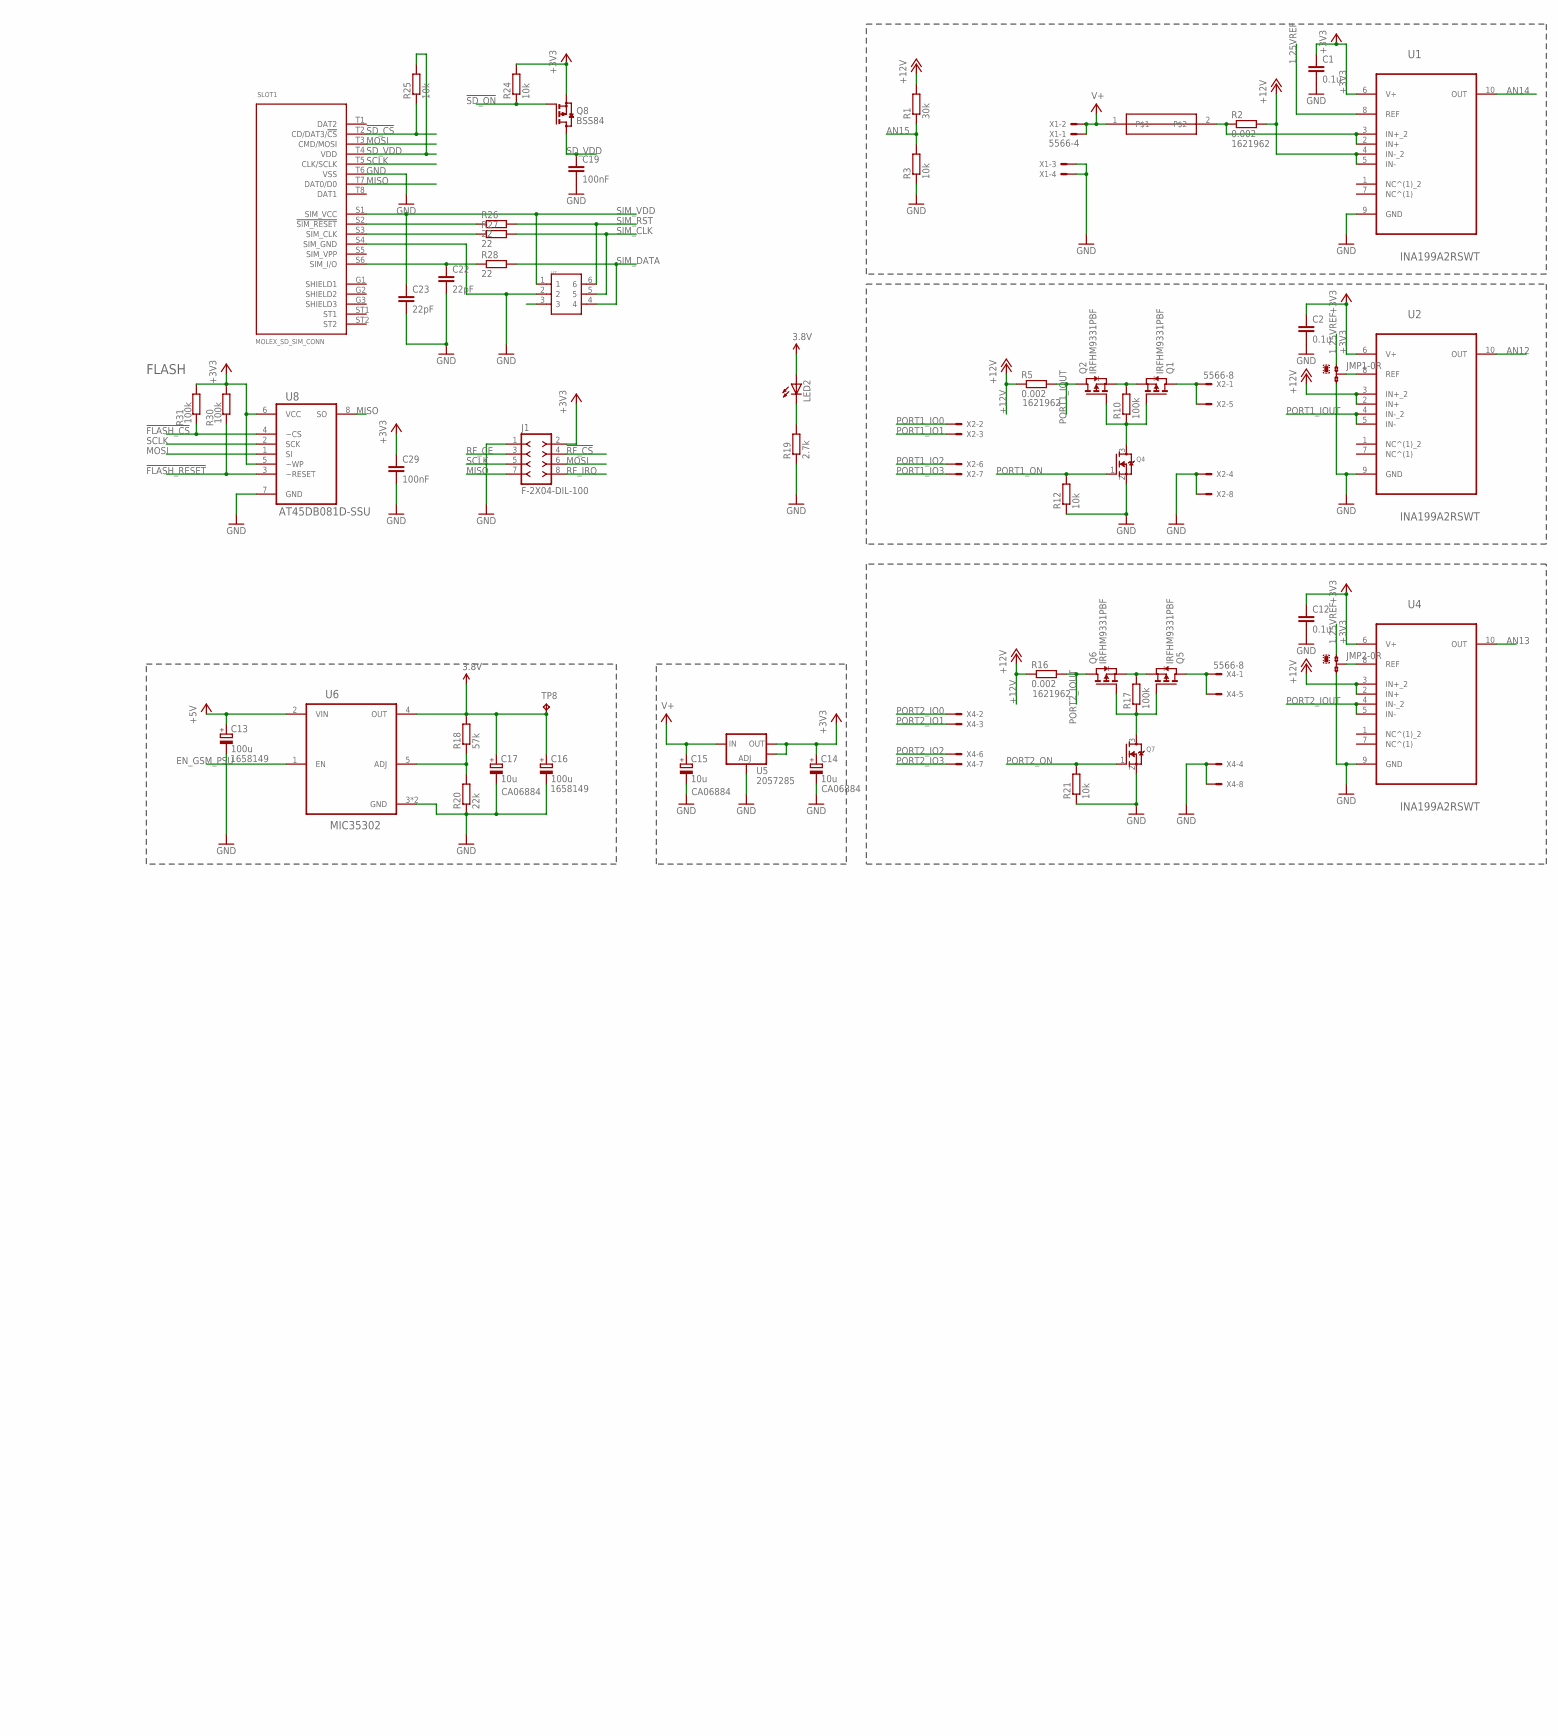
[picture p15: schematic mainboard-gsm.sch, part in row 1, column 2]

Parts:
ANT1: U.FL
BAT1: CR2032-HOLDER; CH28-2032L
C1, C2, C3, C12: 0.1u; C0603
C4: 3300pF; C0603; FARNELL 1658867
C5: 0.47uF; C0805; FARNELL 1907325
C6: 1000pF; C0603
C7: 22u; C1812; FARNELL 1843167
C8, C9: 22u; C1812
C10: 1u; C0805
C11: 100u; C1210; FARNELL 1907361
C13, C16: 100u; B/3528-21R; FARNELL 1658149
C14, C15, C17: 10u; D/7343-31R; FARNELL CA06884
C18: 10uF; C0805
C19, C20, C21, C24, C26, C27, C28, C29, C30, C31, C32, C34, C35, C36, C43: 100nF; C0603
C22, C23: 22pF; C0603
C25: 0.47uF; C1206
C33: 0.47u; C0805
C37: 4.7uF; C0805
C38: 10nF; C0603
C39: 10pF; C0603
C40: 8.2pF; C0603
C41: 39pF; C0603
C42: 33pF; C0603
CONN1: MINIBLADE_SOCKET; LTF153008
D1: 6CWQ04FNPBF; TO252-AA; FARNELL 9101055
D2: DIODESOD-123; SOD-123
IC1: PIC24FJ256GB108; TQFP80-12X12; MPN PIC24FJ256GB108-I/PT
IC2: SIM900_LITERAL; SIM900_SMT
J1: F-2X04-DIL-100; DIL-100-2X04
J2: M-1X06-SIP-100-40; SIP-100-06-40
JMP1, JMP2: 0R-JUMPA; A0R-JMP
L1: 22uH; HC9-XXX-R; FARNELL 2075650
LED1, LED2, LED3, LED4, LED5: LEDCHIPLED_0805; CHIPLED_0805
Q1, Q2, Q5, Q6: IRFHM9331PBF; IR_PQFN_FET
Q3: SI4401BDY; SO8-FET; FARNELL 2101443
Q4, Q7, Q10: MOSFET-NREFLOW; SOT23
Q8: BSS84; SOT23; FARNELL 1972673
Q9: 2N2007; SOT23
R1: 30k; R0805
R2, R5, R16: 0.002; R1206; FARNELL 1621962
R3: 10k; R0805
R4: 2k; R0805
R6: 68k; R0603; FARNELL 1399961
R7, R19: 2.7k; R0805
R8: 3k; R0805
R9: 10m; R1206; FARNELL 1099907
R10, R17, R30, R31: 100k; R0603
R11: 10k; R0805; FARNELL 1653284
R12, R21, R24, R25, R29: 10k; R0603
R13: 2.37k; R0805; FARNELL 1652973
R14: 88.7k; R0603; FARNELL 1170981
R15: 3.4k; R0805; FARNELL 1160169
R18: 57k; R0603
R20: 22k; R0603
R22, R23: 2.7k; R0603
R26, R27, R28: 22; R0603
R32, R33, R34: 300; R0603
R35, R36, R37, R38: 2K7; R0603
SLOT1: MOLEX_SD_SIM_CONN; MOLEX_SDSIM_COMBO
TP1, TP8: TPTP09R; TP09R
TP2, TP3, TP4, TP5, TP6, TP7, TP9, TP10: TPTP10R; TP10R
U1: INA199A2RSWT; QFN40P140X180X55-10N; MPN INA199A2RSWT
U2, U4: INA199A2RSWT; QFN40P140X180X55-10N
U3: LM25085MME; MINI-SO8; FARNELL 1689554
U5: V_REG_LM1117SOT223; SOT223; FARNELL 2057285
U6: MIC35302; TO252-5; FARNELL 1822373
U7: SMF05C'-SC70'; SC70-6L
U8: AT45DB081D-SSU; SOIC127P600X175-8N
U9: REF3012AIDBZT; SOT95P237X112-3N
U10: SN74LVC07APW; SOP65P640X120-14N
U11: MMA8453Q; QFN50P300X300X100-16N
USB1: MOLEX47346-0001; 47346-0001
X1: 5566-4
X2, X4: 5566-8
X3: 5566-2
X5: 53398-05
Y1: TXC-7B

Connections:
1.25VREF: IC1.23 (RA9), JMP1.1, JMP2.1, U1.8 (REF), U9.2 (OUT)
2.8V: IC2.P$15 (VDD_EXT), R35.2, R36.2, R37.2, R38.2
3.8V: C16.+, C17.+, C38.2, C39.2, C40.2, C41.2, C42.2, C43.2, IC2.P$55 (VBAT1), IC2.P$56 (VBAT2), IC2.P$57 (VBAT3), LED2.A, LED3.A, LED4.A, LED5.A, R18.2, TP8.TP, U6.4 (OUT)
!FLASH_CS!: IC1.80 (RE4), R31.2, U8.4 (~CS)
!FLASH_RESET!: IC1.1 (RE5), R30.2, U8.3 (~RESET)
!MCLR!: IC1.9 (!MCLR), J2.1, R29.2
!RF_CS!: IC1.78 (RE2), J1.4
!SD_CS!: IC1.2 (RE6), R25.1, SLOT1.T2 (CD/DAT3/!CS!)
!SD_ON!: IC1.3 (RE7), Q8.1 (G), R24.1
+3V3: C1.1, C2.1, C12.1, C14.+, C24.1, C26.2, C27.2, C29.1, C30.1, C31.1, C32.1, C33.1, C34.1, C37.1, IC1.12 (VDD), IC1.25 (AVDD), IC1.32 (VDD), IC1.45 (VUSB), IC1.48 (VDD), IC1.71 (ENVREG), J1.2, J2.2, Q8.2 (S), R22.2, R23.2, R24.2, R30.1, R31.1, U1.6 (V+), U2.6 (V+), U4.6 (V+), U5.2 (OUT), U5.4 (OUT), U8.5 (~WP), U8.6 (VCC), U9.1 (IN), U10.14 (VCC), U11.1 (VDDIO), X5.1
+5V: C4.1, C11.1, C13.+, L1.2, LED1.A, R4.2, R11.2, TP1.TP, U6.2 (VIN), X3.1
+12V: C5.1, C6.1, C7.1, C8.1, C9.1, C10.1, R1.2, R2.2, R5.1, R9.1, R13.1, R14.1, R16.1, TP3.TP, U1.4 (IN-_2), U1.5 (IN-), U2.2 (IN+), U2.3 (IN+_2), U3.8 (VIN), U4.2 (IN+), U4.3 (IN+_2)
AN12: IC1.33 (TCK), U2.10 (OUT)
AN13: IC1.34 (TDI), U4.10 (OUT)
AN14: IC1.35 (RB14), U1.10 (OUT)
AN15: IC1.36 (RB15), R1.1, R3.2
AXMTR_INT1: IC1.65 (RD13), U11.11 (INT1)
AXMTR_INT2: U11.9 (INT2)
AXMTR_ON: C36.1, IC1.54 (RD8), U11.14 (VDD)
DBG_RXD: IC2.P$28 (DBG_RXD), R38.1, U10.2 (1Y)
DBG_RXD_H: TP9.TP, U10.1 (1A)
DBG_TXD: IC2.P$27 (DBG_TXD), TP10.TP
EN_GSM_PSU: IC1.24 (RA10), U6.1 (EN)
GND: ANT1.P$1 (GND), ANT1.P$2 (GND), BAT1.N (-), C1.2, C2.2, C7.2, C8.2, C9.2, C10.2, C11.2, C12.2, C13.-, C14.-, C15.-, C16.-, C17.-, C18.1, C19.2, C20.1, C21.1, C22.2, C23.2, C24.2, C25.1, C26.1, C27.1, C28.1, C29.2, C30.2, C31.2, C32.2, C33.2, C34.2, C35.2, C36.2, C37.2, C38.1, C39.1, C40.1, C41.1, C42.1, C43.1, D1.1 (A1), D1.3 (A2), IC1.11 (VSS), IC1.26 (AVSS), IC1.31 (VSS), IC1.51 (VSS), IC2.P$17 (GND1), IC2.P$18 (GND2), IC2.P$29 (GND3), IC2.P$39 (GND4), IC2.P$45 (GND5), IC2.P$46 (GND6), IC2.P$53 (GND7), IC2.P$54 (GND8), IC2.P$58 (GND9), IC2.P$59 (GND10), IC2.P$61 (GND11), IC2.P$62 (GND12), IC2.P$63 (GND13), IC2.P$64 (GND14), IC2.P$65 (GND15), J1.1, J2.3, JMP1.3, JMP2.3, Q4.2 (S), Q7.2 (S), Q9.2 (S), Q10.2 (S), R3.1, R7.1, R8.1, R12.1, R15.1, R19.1, R20.1, R21.1, R29.1, R34.1, SLOT1.S4 (SIM_GND), SLOT1.T6 (VSS), TP6.TP, TP7.TP, U1.9 (GND), U2.9 (GND), U3.4 (GND), U4.9 (GND), U5.1 (ADJ), U6.3 (GND), U6.TAB (GND), U7.2, U8.7 (GND), U9.3 (GND), U10.7 (GND), U11.5 (GND_5), U11.7 (SA0), U11.10 (GND_10), U11.12 (GND_12), U11.15 (GND_15), USB1.5 (GND), X1.3, X1.4, X2.4, X2.8, X3.2, X4.4, X4.8, X5.5, Y1.2 (4), Y1.4
GPIO11: IC2.P$67 (GPIO11)
GPIO12: IC2.P$68 (GPIO12)
GSM_CTS: IC1.13 (TMS), IC2.P$7 (CTS)
GSM_DCD: IC1.14 (TDO), IC2.P$5 (DCD)
GSM_DTR: IC2.P$3 (DTR), R35.1, U10.10 (5Y)
GSM_DTR_H: IC1.15 (RB5), U10.11 (5A)
GSM_RESET: IC2.P$16 (NRESET), U10.4 (2Y)
GSM_RESET_H: IC1.20 (RB0), U10.3 (2A)
GSM_RI: IC1.19 (RB1), IC2.P$4 (RI)
GSM_RTS: IC2.P$8 (RTS), R36.1, U10.12 (6Y)
GSM_RTS_H: IC1.16 (RB4), U10.13 (6A)
GSM_RXD: IC2.P$10 (RXD), R37.1, U10.6 (3Y)
GSM_RXD_H: IC1.18 (RB2), U10.5 (3A)
GSM_STATUS: IC2.P$66 (STATUS), Q9.1 (G)
GSM_STATUS_H: Q9.3 (D), R33.1
GSM_TXD: IC1.5 (RC3), IC2.P$9 (TXD)
MISO: IC1.8 (RG8), J1.7, SLOT1.T7 (DAT0/D0), U8.8 (SO)
MOSI: IC1.6 (RG6), J1.6, SLOT1.T3 (CMD/MOSI), U8.1 (SI)
unnamed: C35.1, U11.2 (BYP)
unnamed: R26.1, SLOT1.S2 (!SIM_RESET!)
unnamed: R27.1, SLOT1.S3 (SIM_CLK)
unnamed: C22.1, R28.1, SLOT1.S6 (SIM_I/O)
unnamed: ANT1.P$3 (SIGNAL), IC2.P$60 (RF_ANT)
unnamed: Q10.3 (D), R32.1
unnamed: LED5.C, R33.2
unnamed: LED4.C, R32.2
unnamed: BAT1.P (+), D2.A
unnamed: Q3.4 (G), TP4.TP, U3.6 (PGATE)
unnamed: D1.4 (C), L1.1, Q3.5 (D), Q3.6 (D), Q3.7 (D), Q3.8 (D), Q3.D1 (D), Q3.D2 (D), Q3.D3 (D), R6.1
unnamed: Q5.1 (S), Q5.2 (S), Q5.3 (S), Q5.3B (S), Q6.1 (S), Q6.2 (S), Q6.3 (S), Q6.3B (S), R17.2
unnamed: C5.2, U3.7 (VCC)
unnamed: Q3.1 (S), Q3.2 (S), Q3.3 (S), R9.2, TP2.TP, U3.5 (ISEN)
unnamed: Q5.4 (G), Q6.4 (G), Q7.3 (D), R17.1
unnamed: C6.2, R13.2, U3.1 (ADJ)
unnamed: JMP1.2, U2.8 (REF)
unnamed: Q5.5 (D), Q5.6 (D), Q5.7 (D), Q5.8 (D), Q5.9 (D), X4.1, X4.5
unnamed: Q1.1 (S), Q1.2 (S), Q1.3 (S), Q1.3B (S), Q2.1 (S), Q2.2 (S), Q2.3 (S), Q2.3B (S), R10.2
unnamed: Q1.4 (G), Q2.4 (G), Q4.3 (D), R10.1
unnamed: C3.1, C4.2, R6.2
unnamed: C3.2, R11.1, R15.2, TP5.TP, U3.3 (FB)
unnamed: LED3.C, R34.2
unnamed: Q1.5 (D), Q1.6 (D), Q1.7 (D), Q1.8 (D), Q1.9 (D), X2.1, X2.5
unnamed: R18.1, R20.2, U6.5 (ADJ)
unnamed: CONN1.2, R2.1, U1.2 (IN+), U1.3 (IN+_2)
unnamed: JMP2.2, U4.8 (REF)
unnamed: LED1.C, R7.2
unnamed: LED2.C, R19.2
unnamed: C18.2, IC1.70 (VDDCORE)
NETLIGHT: IC2.P$52 (NETLIGHT), Q10.1 (G)
OSCI: C21.2, IC1.49 (RC12), Y1.1
OSCO: C20.2, IC1.50 (RC15), Y1.3 (2)
PGEC2: IC1.21 (RB6), J2.5
PGED2: IC1.22 (RB7), J2.4
PORT1_IO0: IC1.57 (RD11), X2.2
PORT1_IO1: IC1.58 (RD0), X2.3
PORT1_IO2: IC1.59 (RC13), X2.6
PORT1_IO3: IC1.60 (RC14), X2.7
PORT1_IOUT: Q2.5 (D), Q2.6 (D), Q2.7 (D), Q2.8 (D), Q2.9 (D), R5.2, U2.4 (IN-_2), U2.5 (IN-)
PORT1_ON: IC1.52 (RA14), Q4.1 (G), R12.2
PORT2_IO0: IC1.61 (RD1), X4.2
PORT2_IO1: IC1.62 (RD2), X4.3
PORT2_IO2: IC1.63 (RD3), X4.6
PORT2_IO3: X4.7
PORT2_IOUT: Q6.5 (D), Q6.6 (D), Q6.7 (D), Q6.8 (D), Q6.9 (D), R16.2, U4.4 (IN-_2), U4.5 (IN-)
PORT2_ON: IC1.53 (RA15), Q7.1 (G), R21.2
PWRKEY: IC2.P$1 (PWRKEY), U10.8 (4Y)
PWRKEY_H: IC1.10 (RG9), U10.9 (4A)
RF_CE: IC1.79 (RE3), J1.3
RF_IRQ: IC1.77 (RE1), J1.8
RPI38: IC1.4 (RC1)
RT: R14.2, U3.2 (RT)
SCL1: IC1.56 (RD10), R22.1, U11.4 (SCL)
SCLK: IC1.7 (RG7), J1.5, SLOT1.T5 (CLK/SCLK), U8.2 (SCK)
SDA1: IC1.55 (RD9), R23.1, U11.6 (SDA)
SD_VDD: C19.1, Q8.3 (D), R25.2, SLOT1.T4 (VDD)
SENSE_5V: IC1.17 (RB3), R4.1, R8.2
SIM_CLK: IC2.P$32 (SIM_CLK), R27.2, U7.5
SIM_DATA: IC2.P$31 (SIM_DATA), R28.2, U7.4
SIM_RST: IC2.P$33 (SIM_RST), R26.2, U7.6
SIM_VDD: C23.1, IC2.P$30 (SIM_VDD), SLOT1.S1 (SIM_VCC), U7.1
U2_RTS: IC1.64 (RD12), X5.4
U2_RXD: IC1.67 (RD5), X5.2
U2_TXD: IC1.66 (RD4), X5.3
UD_N: IC1.46 (RG3), USB1.2 (D-)
UD_P: IC1.47 (RG2), USB1.3 (D+)
USB_VBUS: C25.2, C28.2, IC1.44 (VBUS), USB1.1 (VBUS)
V+: C15.+, CONN1.1, U5.3 (IN), X1.1, X1.2
VRTC: D2.C, IC2.P$26 (VRTC)

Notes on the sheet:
MMA8453 3Axis Accelerometer
Address: 0x1C
Farnell 1842361
FLASH

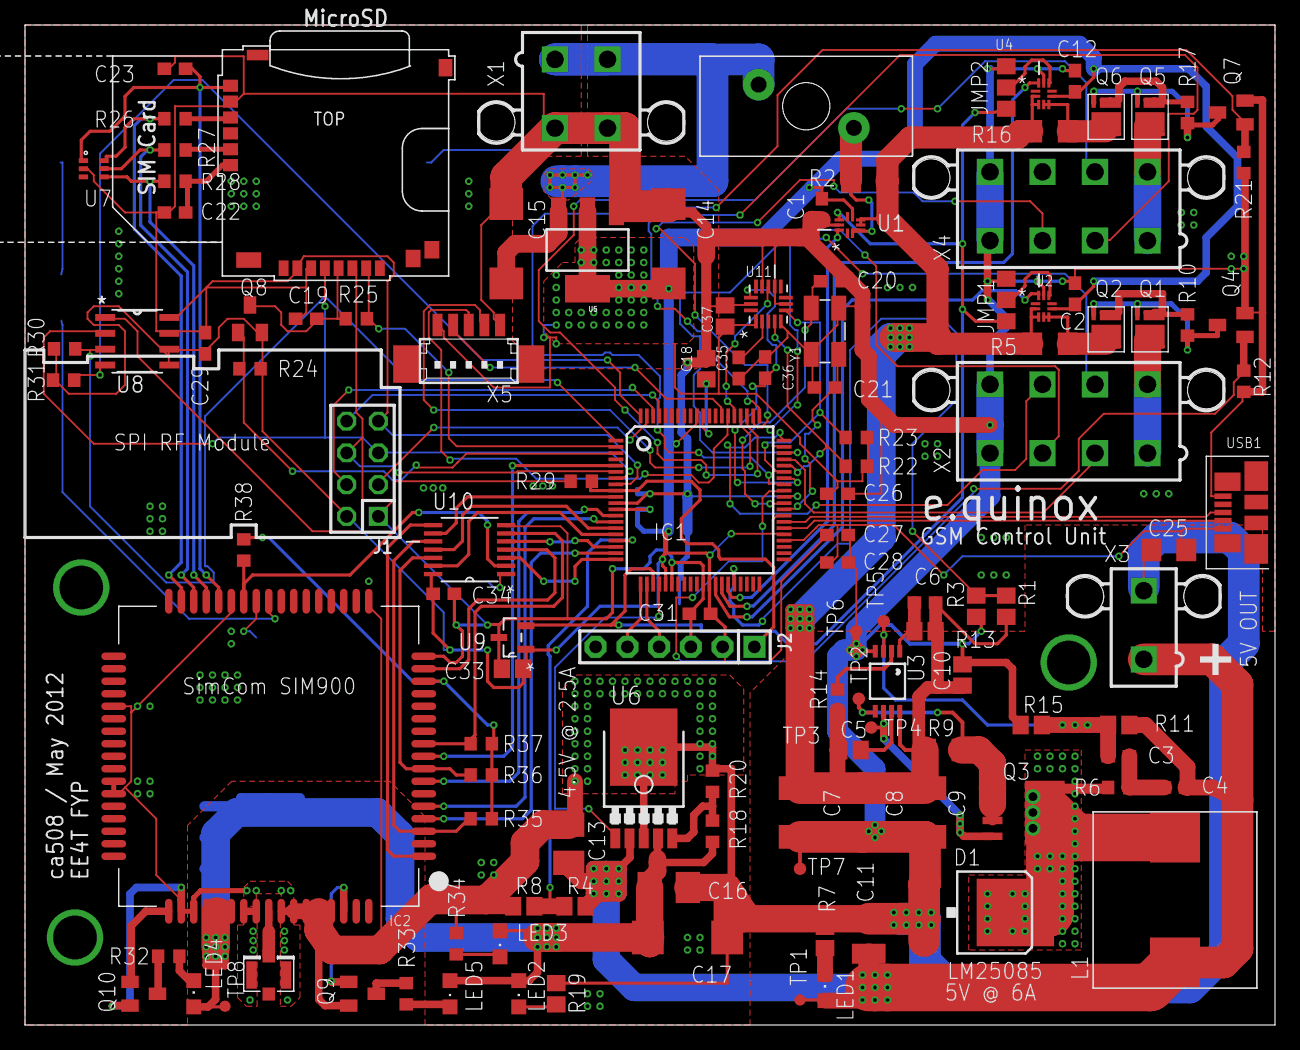
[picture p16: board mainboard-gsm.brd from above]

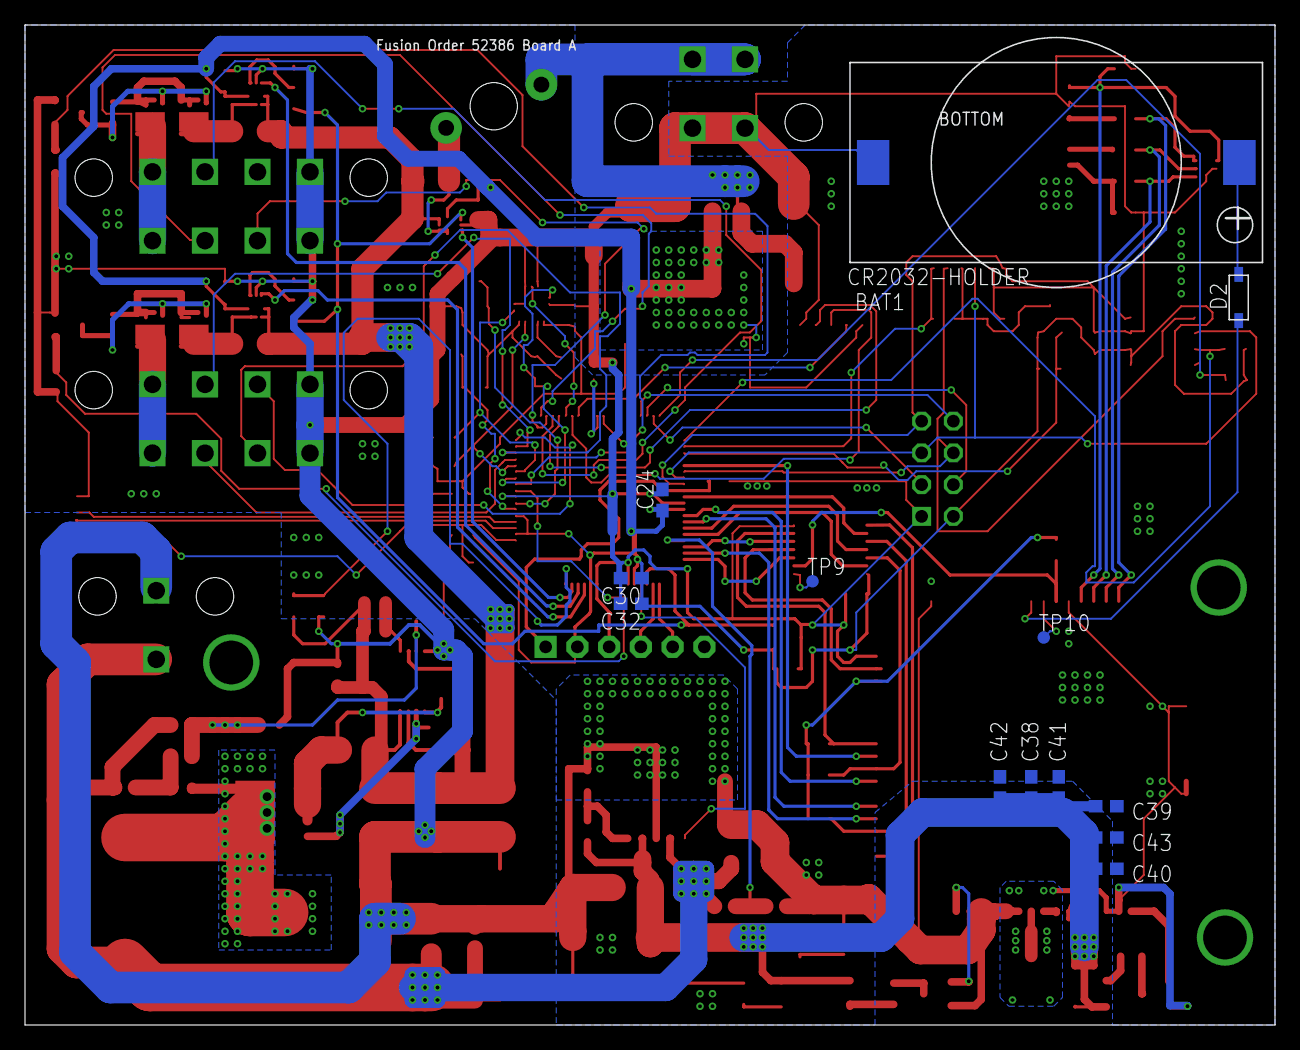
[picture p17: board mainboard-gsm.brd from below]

Board: 2 copper layers, 100.0 x 80.0 mm, 137 parts (13 on the bottom side), 107 nets.

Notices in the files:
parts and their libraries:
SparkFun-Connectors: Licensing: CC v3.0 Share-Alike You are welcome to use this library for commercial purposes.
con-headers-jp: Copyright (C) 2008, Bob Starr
